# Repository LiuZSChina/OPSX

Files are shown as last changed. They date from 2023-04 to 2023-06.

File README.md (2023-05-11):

# OPSX Sonnar
An open sourced Polaroid SX-70 core board with sonnar support.Based on the [OPSX project](https://github.com/sunyitong/OPSX).\
开源的宝丽来sx-70核心板，可以支持带有声呐对焦的设备。基于[OPSX 项目](https://github.com/sunyitong/OPSX)开发。

This is an open sourced Polaroid SX-70 instant camera core board with the Raspberry Pi RP2040 as the MCU. The aim of this project is to provide a fully resource accessible and hobbyist friendly replacement core board. It offers more extensibility and hacking ideas while implementing all the features of the original camera.\
本项目是开源的宝丽来sx-70核心板，该项目使用树莓派rp2040构建而成，本项目的目的是为爱好者提供一个可以完全自主掌控的核心板，在保留原机器各种功能的同时可以发挥自己的创意进行功能拓展。

The structure of the repository:\
本项目仓库的结构：

1. The [Original](https://github.com/LiuZSChina/OPSX/tree/master/Original) file contains design for non-sonnar sx-70.See README.md inside this folder for details.\
[Original](https://github.com/LiuZSChina/OPSX/tree/master/Original)文件夹内是适合没有声呐对焦sx70的核心板设计，设计来自于原本的[OPSX 项目](https://github.com/sunyitong/OPSX)，文件夹内具体项目的作用详见文件夹内的README.md

2. The [Sonar](https://github.com/LiuZSChina/OPSX/tree/master/Sonnar) file contains design for sonnar sx-70.See README.md inside this folder for details.\
[Original](https://github.com/LiuZSChina/OPSX/tree/master/Original)文件夹内是新设计的适用于声呐对焦的sx70核心板及附件，文件夹内具体项目的作用详见文件夹内的README.md。

## Table of Contents

- [OPSX](#opsx)
  - [Hardware](#hardware)
    - [Fabrication](#fabrication)
  - [Software](#software)
    - [Uploading](#uploading)
  - [Contributor](#contributor)
  - [License](#license)

## Hardware
> Remander: You are going to need some “basic” tools:   soldering iron with a fine tip, a prying tool and a tweezer.\
Aside from the usual tools you are going to need what is called a “Polaroid screwdriver” or “SX-70 screwdriver”, since most of the cameras use a special “square 1mm x 1mm” screws. You could either buy one or fabricate one yourself.\
please read the [Disassembly Guide](https://instantphotography.files.wordpress.com/2010/12/polaroid-sx-70-camera-repair-book.pdf) or [SX70 camera 125ASA to 600ASA conversion](https://opensx70.com/tutorials/100-600-conversion/) first.\
提示：首先你需要一些基本的工具：电烙铁、撬棒和镊子。\
其次大多数sx70相机的螺丝都是非常特殊的1mm x 1mm 宝丽来螺丝，所以你需要使用特殊的螺丝刀才能拆卸，买一把或者自己磨一个都可以。\
在操作之前推荐先浏览[Disassembly Guide](https://instantphotography.files.wordpress.com/2010/12/polaroid-sx-70-camera-repair-book.pdf) 或者 [SX70 camera 125ASA to 600ASA conversion](https://opensx70.com/tutorials/100-600-conversion/).

### Fabrication
Please select a **dual copper layer PCB** with a thickness of **0.8 mm** or less for fabrication.\
制造时请选择 FR-4基板，双层板，厚度0.8mm或者更小（会贵）。

## Software
TODO

### Uploading
Solder U+ U- GND VCC to a standard usb cable to connect to your computer. Then you can treat it as normal raspberry pico device. See [here](https://www.raspberrypi.com/documentation/microcontrollers/rp2040.html#raspberry-pi-pico) for more information about uploading.\
把板子上的U+ U- GND VCC焊到usb线上，连接电脑后可以当作树莓派Pico开发板进行操作，具体上传的方法在[这里](https://www.raspberrypi.com/documentation/microcontrollers/rp2040.html#raspberry-pi-pico)。

## Contributor
[@Yitong Sun](https://github.com/sunyitong) - a PhD candidate in the Computer Science Research Centre at the Royal College of Art.[RCA website](https://www.rca.ac.uk/research-innovation/research-degrees/research-students/yitong-sun/) - [E-mail](yitong.sun@network.rca.ac.uk)

[@LiuZS](https://github.com/LiuZSChina) - ？
## License
Any distribution or modification based on this project should be clearly attributed to the source.
[GPL 3.0](LICENSE)

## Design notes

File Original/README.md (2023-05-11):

# OPSX
An open sourced Polaroid SX-70 core board

This is an open sourced Polaroid SX-70 instant camera core board with the Raspberry Pi RP2040 as the MCU. The aim of this project is to provide a fully resource accessible and hobbyist friendly replacement core board. It offers more extensibility and hacking ideas while implementing all the features of the original camera.

The structure of the repository:

1. The [bom](https://github.com/LiuZSChina/OPSX/tree/master/Original/bom) folder contains an html-based interactive bill of material. You can use it to find the component types and locations

2. The [code](https://github.com/LiuZSChina/OPSX/tree/master/Original/code) folder holds the program files necessary to run the core board. The programs are implemented in two separate programming languages:

   - [Micropython](https://docs.micropython.org/en/latest/rp2/quickref.html): Similar syntax to python, easy to modify and testing.
   - [Rust](https://docs.rs/rp2040/latest/rp2040/) (TODO): Ultimate performance with zero runtime loss.

3. The [gerber](https://github.com/LiuZSChina/OPSX/tree/master/Original/gerber) folder stores the PCB files necessary for factory production.

4. The [schematic](https://github.com/LiuZSChina/OPSX/tree/master/Original/schematic) folder holds a PDF file which illustrating the circuit principles.

## Table of Contents

- [OPSX](#opsx)
  - [Table of Contents](#table-of-contents)
  - [Hardware](#hardware)
    - [Fabrication](#fabrication)
  - [Software](#software)
    - [Uploading](#uploading)
  - [Contributor](#contributor)
  - [License](#license)

## Hardware
TODO
> Remander: Special tools are required to replace the original core board, please read the [Disassembly Guide](https://instantphotography.files.wordpress.com/2010/12/polaroid-sx-70-camera-repair-book.pdf) first.
### Fabrication
Please select a **dual copper layer PCB** with a thickness of **0.8 mm** or less for fabrication.
## Software
TODO
### Uploading
TODO
## Contributor
[@Yitong Sun](https://github.com/sunyitong) - a PhD candidate in the Computer Science Research Centre at the Royal College of Art.

[RCA website](https://www.rca.ac.uk/research-innovation/research-degrees/research-students/yitong-sun/) - [E-mail](yitong.sun@network.rca.ac.uk)
## License
Any distribution or modification based on this project should be clearly attributed to the source.
[GPL 3.0](LICENSE) © Yitong Sun

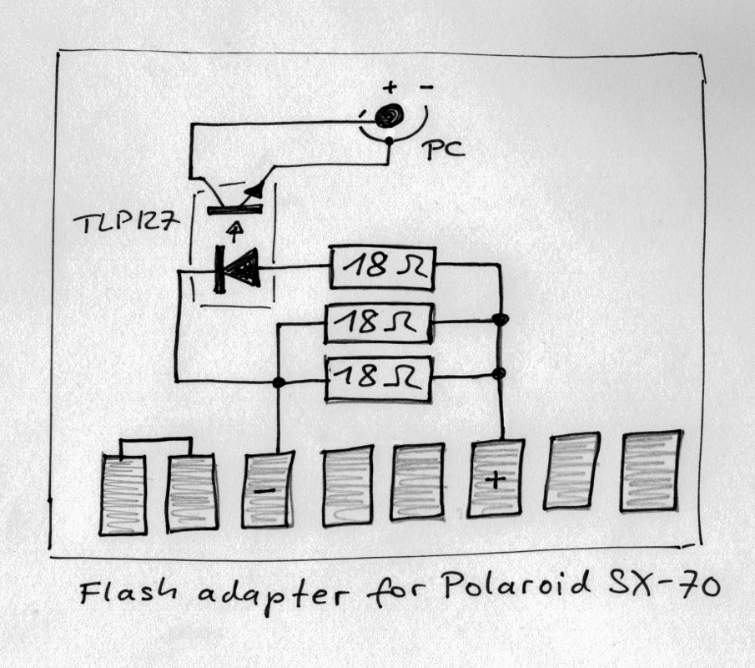
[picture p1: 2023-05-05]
Sonnar/Flash_Plug/adaptercircuit2.jpg

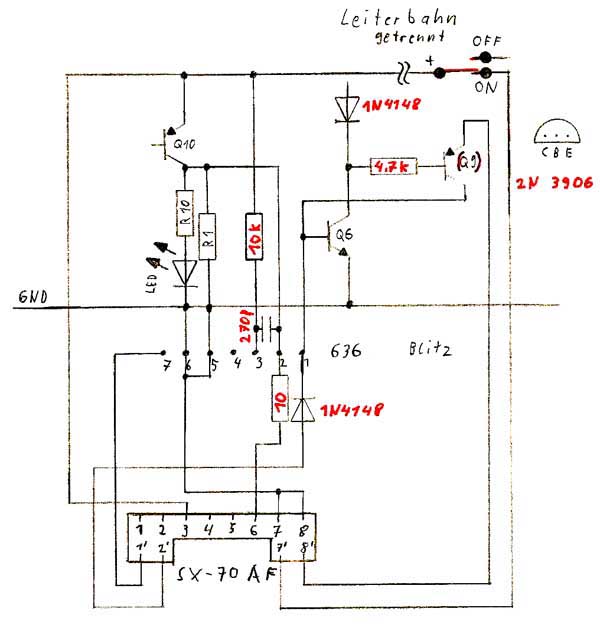
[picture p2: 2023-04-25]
Sonnar/Flash_Plug/Flash-schaltplan2.jpg

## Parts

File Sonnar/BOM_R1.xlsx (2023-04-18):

Comment | Designator | Footprint | 嘉立创元件编号
100nF | C1,C2,C4,C6,C7,C8,C9,C10,C11,C12,C14 | 0402_C | C307331
1uF | C3,C5,C13 | 0402_C | C52923
13pF | C15 | 0402_C | C541433
1N4148WS | D1,D3,D4 | D_SOD-323 | C2128
LED | D5 | 0603_D | C72041
LED | D6 | 0603_D | C72038
Q_NMOS_GSD | Q1,Q2 | SOT-23 | C23521
Q_PMOS_GSD | Q3 | SOT-23 | C8549
MMBT3904 | Q4 | SOT-23 | C20526
27.4Ω | R1,R2 | 0402_R | C102945
1kΩ | R3,R26,R27,R35 | 0402_R | C11702
10kΩ | R4,R6,R9,R11,R12,R13,R15,R17,R19 | 0402_R | C25744
12kΩ | R5,R10,R14,R16,R18,R20 | 0402_R | C25752
22kΩ | R7 | 0805_R | C25768
100kΩ | R8,R23,R25,R28 | 0402_R | C25741
120Ω | R21,R22,R24 | 0402_R | C25079
180Ω | R29 | 0402_R | C174173
150Ω | R30 | 0402_R | C25082
5.6kΩ | R31 | 0402_R | C25908
47kΩ | R32 | 0402_R | C25792
2.7kΩ | R33 | 0402_R | C352444
330Ω | R34 | 0402_R | C25104
RP2040 | U1 | LQFN-56(7x7) | C2040
TLV70430DBVR | U2 | SOT-23-5 | C133625
W25Q128JVS | U3 | SOIC-8_5.23x5.23mm_P1.27mm | C97521
AD8605 | U5,U6 | TSOT-23-5 | C9641
Crystal_GND2 | Y1 | Resonator_SMD_Murata_CSTxExxV-3Pin_3.0x1.1mm | C91581

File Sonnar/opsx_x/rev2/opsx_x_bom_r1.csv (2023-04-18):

ID | 指示符 | 封装 | 数量 | 名称 | 供应商和参考
1 | U4 | TMB6-1.55-3.8X2.6MM | 1 | OPTICAL-TSL2561T(6P-3.8X2.6MM)
2 | U2 | DBV0005A_N | 1 | TLV70430DBVR
3 | R35,R27,R26,R3 | R_0402_1005Metric_Pad0.72x0.64mm_HandSolder | 4 | 1k
4 | D6,D5 | D_0603_1608Metric_Pad1.05x0.95mm_HandSolder | 2 | LED
5 | R34 | R_0402_1005Metric_Pad0.72x0.64mm_HandSolder | 1 | 330
6 | Q3 | SOT-23 | 1 | Q_PMOS_GSD
7 | R33 | R_0402_1005Metric_Pad0.72x0.64mm_HandSolder | 1 | 2.7k
8 | R32 | R_0402_1005Metric_Pad0.72x0.64mm_HandSolder | 1 | 47k
9 | R31 | R_0402_1005Metric_Pad0.72x0.64mm_HandSolder | 1 | 5.6k
10 | Q4 | SOT-23 | 1 | MMBT3904
11 | Z3,Z2,Z1 | Selector_default | 3 | ~
12 | R30 | R_0402_1005Metric_Pad0.72x0.64mm_HandSolder | 1 | 150
13 | R29 | R_0402_1005Metric_Pad0.72x0.64mm_HandSolder | 1 | 180
14 | C15 | C_0402_1005Metric_Pad0.74x0.62mm_HandSolder | 1 | 13p
15 | U6,U5 | TSOT-23-5 | 2 | AD8603
16 | R28,R8,R25,R23 | R_0402_1005Metric_Pad0.72x0.64mm_HandSolder | 4 | 100k
17 | R7 | R_0805_2012Metric_Pad1.20x1.40mm_HandSolder | 1 | 22k
18 | R10,R16,R14,R18,R5,R20 | R_0402_1005Metric_Pad0.72x0.64mm_HandSolder | 6 | 12k
19 | C8,C14,C6,C2,C10,C12,C7,C1,C9,C11 | C_0402_1005Metric_Pad0.74x0.62mm_HandSolder | 10 | 100n
20 | R12,R15,R6,R19,R9,R17,R11,R4,R13 | R_0402_1005Metric_Pad0.72x0.64mm_HandSolder | 9 | 10k
21 | R1,R2 | R_0402_1005Metric_Pad0.72x0.64mm_HandSolder | 2 | 27.4
22 | Q2,Q1 | SOT-23 | 2 | Q_NMOS_GSD
23 | sx1 | sx70 | 1 | sx~
24 | J2,J1,J3 | PinHeader_1x02_P2.54mm_Vertical | 3 | Conn_01x02
25 | C4 | C_0402_1005Metric_Pad0.74x0.62mm_HandSolder | 1 | 0.1u
26 | Y1 | Resonator_SMD_Murata_CSTxExxV-3Pin_3.0x1.1mm | 1 | Crystal_GND2
27 | D4,D3,D1 | D_SOD-323 | 3 | 1N4148WS
28 | R24,R21,R22 | R_0402_1005Metric_Pad0.72x0.64mm_HandSolder | 3 | 100
29 | U3 | SOIC-8_5.23x5.23mm_P1.27mm | 1 | W25Q128JVS
30 | C3,C13,C5 | C_0402_1005Metric_Pad0.74x0.62mm_HandSolder | 3 | 1u
31 | U1 | RP2040-QFN-56 | 1 | RP2040
32 | D2 | Osram_SFH2430 | 1 | SFH2430

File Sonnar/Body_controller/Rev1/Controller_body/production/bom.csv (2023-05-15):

Designator | Footprint | Quantity | Value | LCSC Part #
Bolt1, Bolt2, Bolt3 | M3_Bolt | 3 | ~
J1 | TE_84953-6_1x06-1MP_P1.0mm_Horizontal | 1 | Conn_01x06_Socket
J2 | PinHeader_1x03_P2.54mm_Horizontal | 1 | Conn_01x03_Socket
R1, R10, R11, R12, R13, R2, R3, R4, R7, R8, R9 | 805 | 11 | 100k
R5, R6 | 805 | 2 | 10k
SW1 | GSMR_16 | 1 | ~
SW2 | GSMR_10S | 1 | ~
SW3 | Direction3 Pin5 | 1 | ~
U1 | SOP65P640X120-24N | 1 | PCF8575PWR
U2 | OLED 0.96 i2c | 1 | ~

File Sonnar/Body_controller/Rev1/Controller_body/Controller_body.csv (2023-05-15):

# | Reference | Qty | Value | Footprint | DNP
1 | Bolt1, Bolt2, Bolt3 | 3 | ~ | 0JIMMY:M3_Bolt
2 | J1 | 1 | Conn_01x06_Socket | Connector_FFC-FPC:TE_84953-6_1x06-1MP_P1.0mm_Horizontal
3 | J2 | 1 | Conn_01x03_Socket | Connector_PinHeader_2.54mm:PinHeader_1x03_P2.54mm_Horizontal
4 | R1, R2, R3, R4, R7, R8, R9, R10, R11, R12, R13 | 11 | 100k | Resistor_SMD:R_0805_2012Metric_Pad1.20x1.40mm_HandSolder
5 | R5, R6 | 2 | 10k | Resistor_SMD:R_0805_2012Metric_Pad1.20x1.40mm_HandSolder
6 | SW1 | 1 | ~ | SW_CODED:GSMR_16
7 | SW2 | 1 | ~ | SW_CODED:GSMR_10S
8 | SW3 | 1 | ~ | SW_CODED:Direction3 Pin5
9 | U1 | 1 | PCF8575PWR | SOP65P640X120-24N
10 | U2 | 1 | ~ | 0JIMMY:OLED 0.96 i2c

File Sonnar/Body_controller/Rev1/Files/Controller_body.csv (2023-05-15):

ID | 指示符 | 封装 | 数量 | 名称 | 供应商和参考
1 | R6,R5 | R_0805_2012Metric_Pad1.20x1.40mm_HandSolder | 2 | 10k
2 | R8,R3,R12,R2,R10,R7,R13,R4,R11,R9,R1 | R_0805_2012Metric_Pad1.20x1.40mm_HandSolder | 11 | 100k
3 | Bolt2,Bolt3,Bolt1 | M3_Bolt | 3 | ~
4 | J1 | TE_84953-6_1x06-1MP_P1.0mm_Horizontal | 1 | Conn_01x06_Socket
5 | SW3 | Direction3 Pin5 | 1 | ~
6 | U2 | OLED 0.96 i2c | 1 | ~
7 | J2 | PinHeader_1x03_P2.54mm_Horizontal | 1 | Conn_01x03_Socket
8 | SW1 | GSMR_16 | 1 | ~
9 | U1 | SOP65P640X120-24N | 1 | PCF8575PWR
10 | SW2 | GSMR_10S | 1 | ~

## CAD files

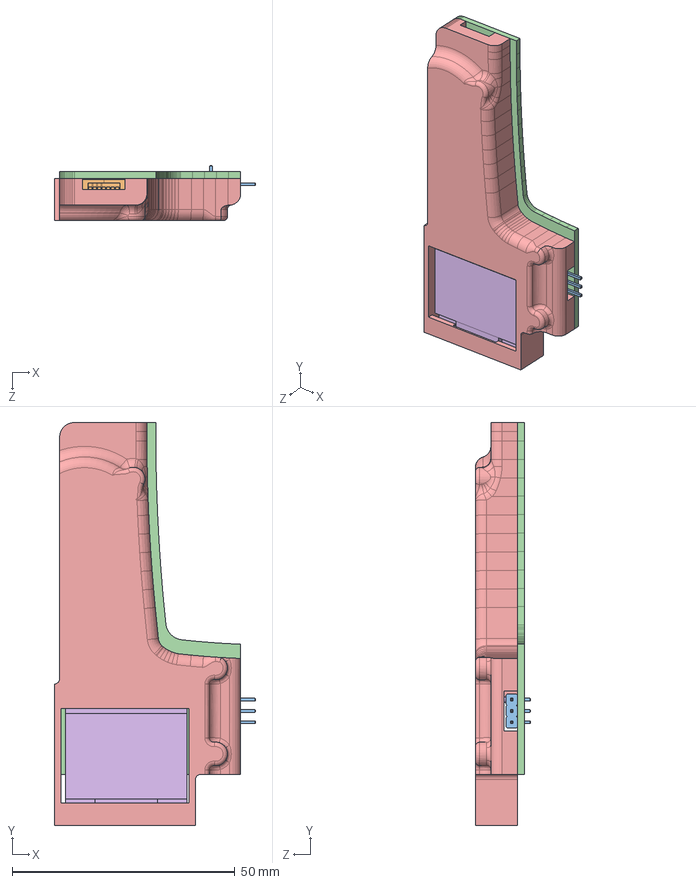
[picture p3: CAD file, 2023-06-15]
Sonnar/Body_controller/Rev1/3D/机身.SLDASM
45.2 x 90.5 x 12.4 mm
SOLID.step x 13
SOLID-0.step
SOLID-1.step
PCB.step
机身壳
oled

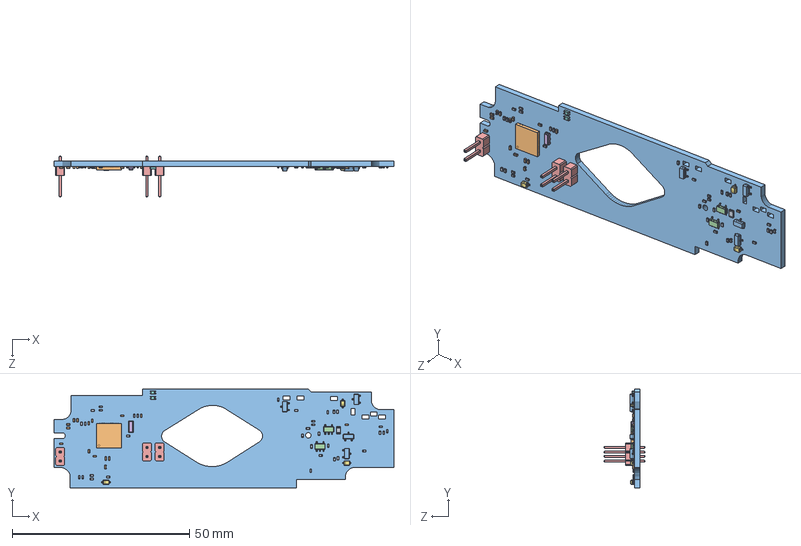
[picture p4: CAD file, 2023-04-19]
Sonnar/3D/opsx_x.SLDASM
95.9 x 27.8 x 11.5 mm
SOLID.step x 34
SOLID-0.step x 15
SOLID-1.step x 4
SOLID-2.step x 2
SOLID-3.step x 3
SOLID-4.step
SOLID-5.step x 3
SOLID-6.step x 2
SOLID-7.step
SOLID-8.step
PCB.step

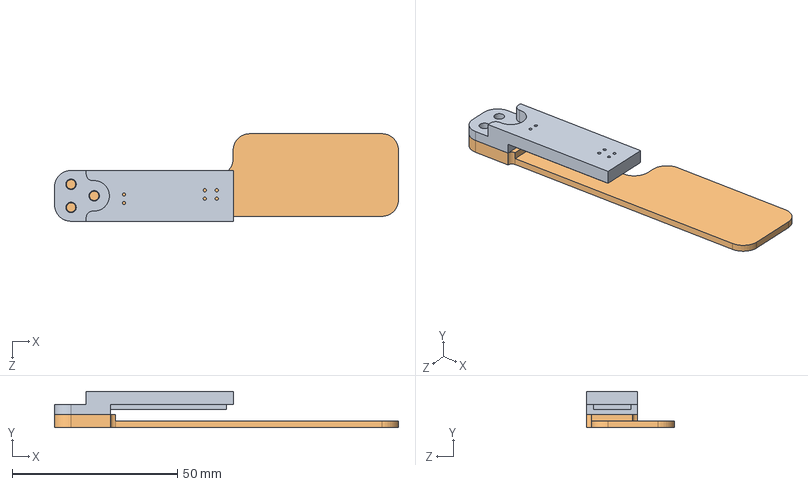
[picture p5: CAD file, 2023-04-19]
Sonnar/3D/测试夹.SLDASM
104.0 x 11.0 x 26.5 mm
测试针
测试针_底

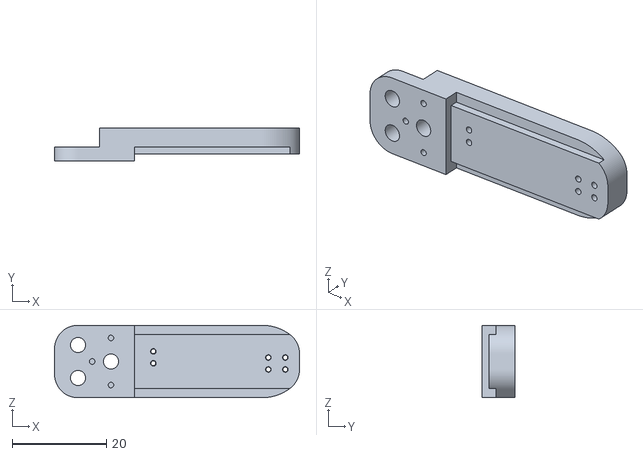
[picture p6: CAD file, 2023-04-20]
Sonnar/3D/Test_Pin_Holder.STL
52.0 x 7.00 x 15.4

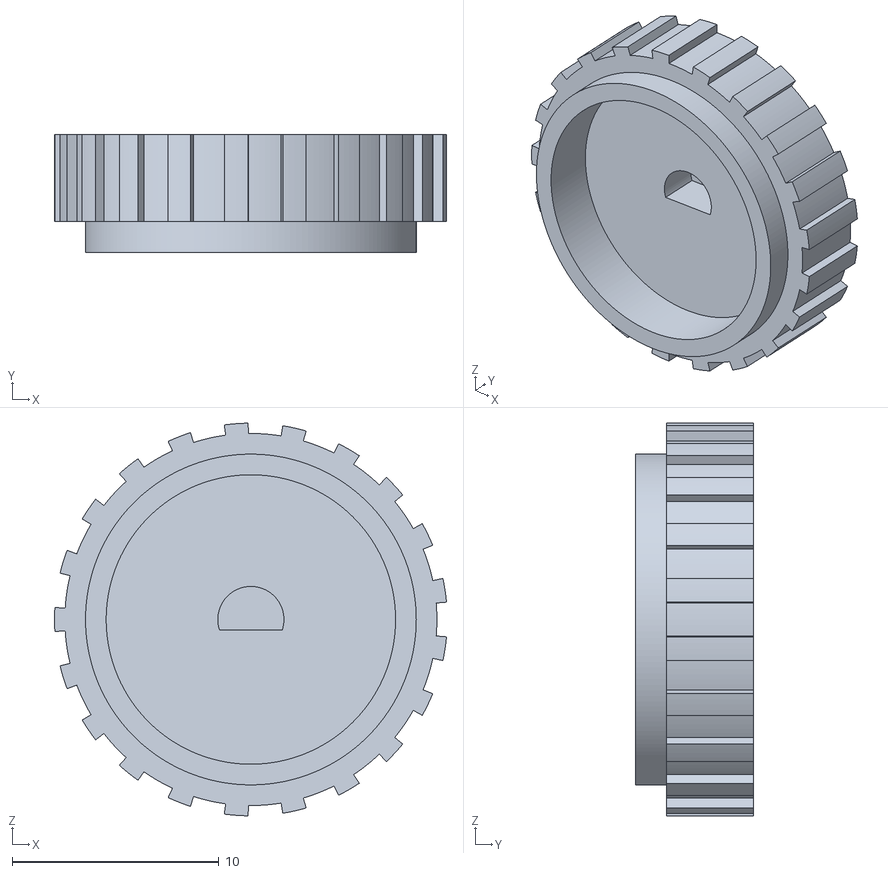
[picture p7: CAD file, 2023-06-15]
Sonnar/Body_controller/Rev1/3D/rot_no_val_th.stl
19.0 x 5.70 x 19.0

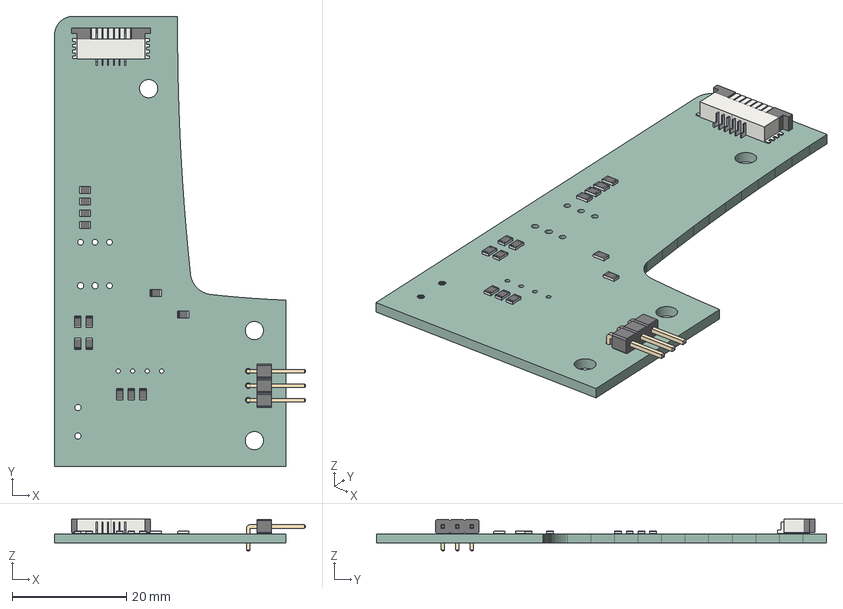
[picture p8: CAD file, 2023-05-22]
Sonnar/Body_controller/Rev1/Controller_body/3D/Controller_body.step
44.0 x 79.0 x 5.56 mm
PCB

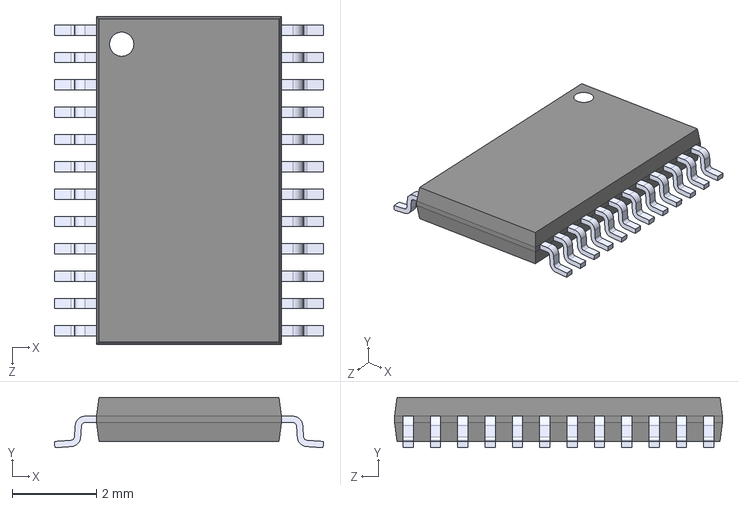
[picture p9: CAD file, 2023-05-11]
Sonnar/Body_controller/Rev1/Controller_body/PCF8575PWR/PCF8575PWR.step
6.40 x 1.20 x 7.80 mm

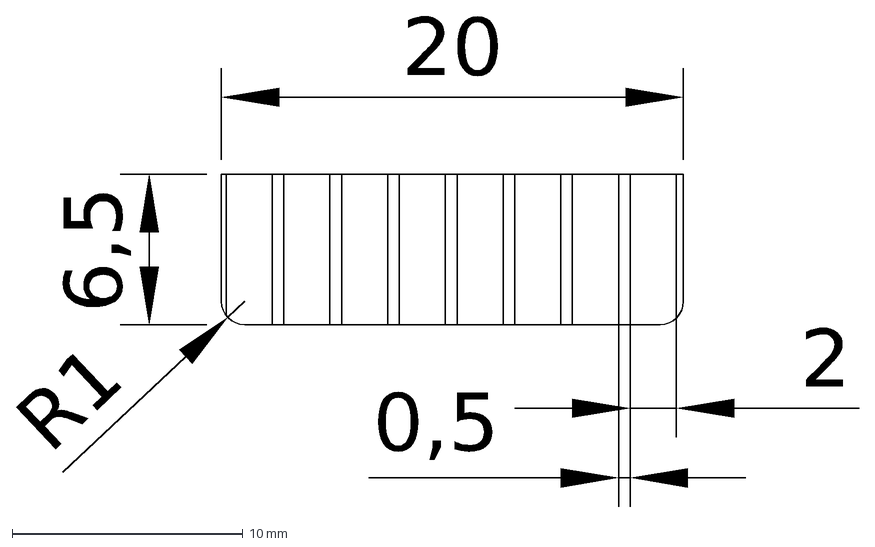
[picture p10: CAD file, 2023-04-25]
Sonnar/Flash_Plug/Flash_Plug_Size.dxf
20
6,5
R1
2
0,5

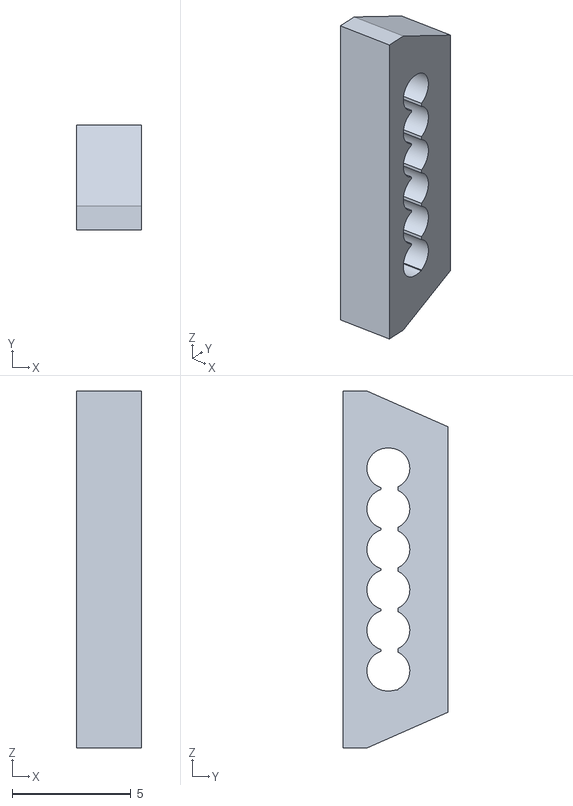
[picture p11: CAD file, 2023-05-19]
Sonnar/opsx_x/3D/line_cliper_round.stl
2.75 x 4.40 x 15.0

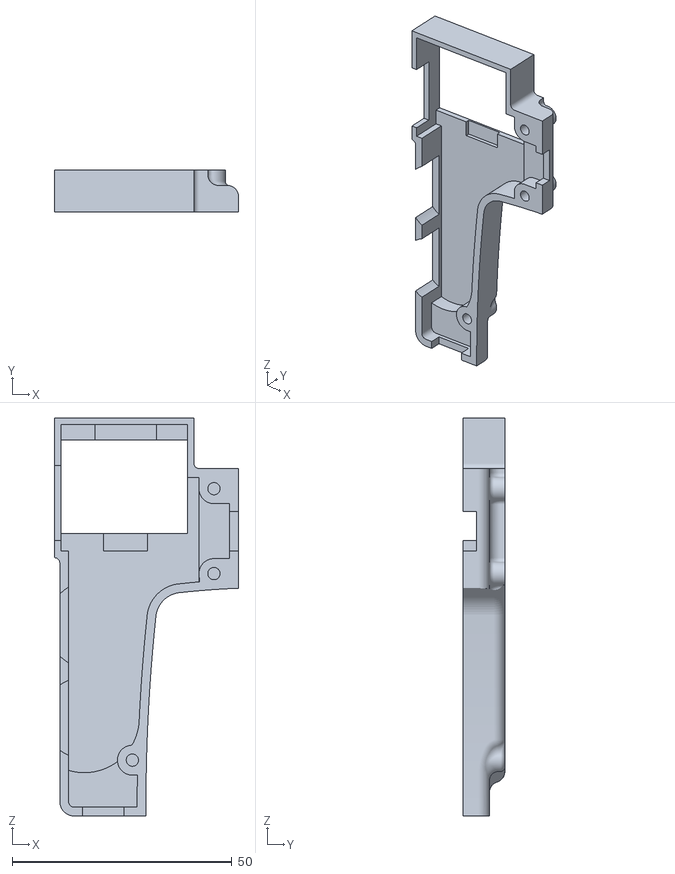
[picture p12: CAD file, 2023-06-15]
Sonnar/Body_controller/Rev1/3D/Case_Body_Control.STL
41.8 x 9.50 x 90.5

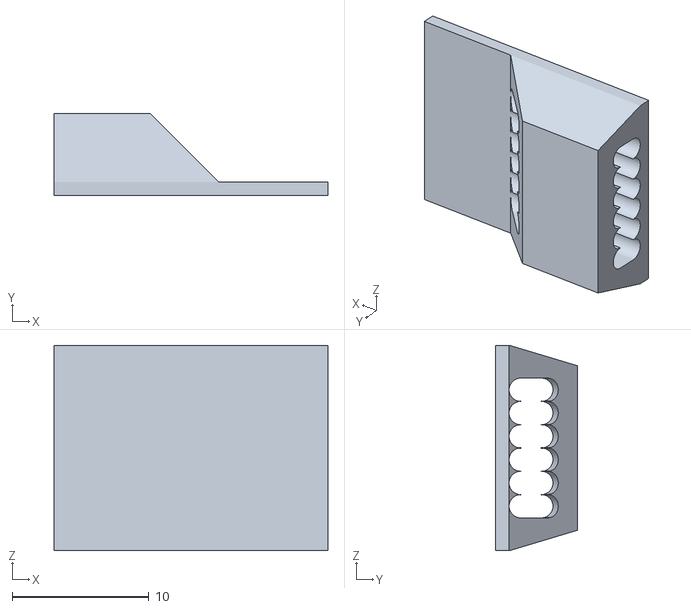
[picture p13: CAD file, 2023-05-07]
Sonnar/opsx_x/3D/line_cliper_reverse.stl
20.0 x 6.00 x 15.0

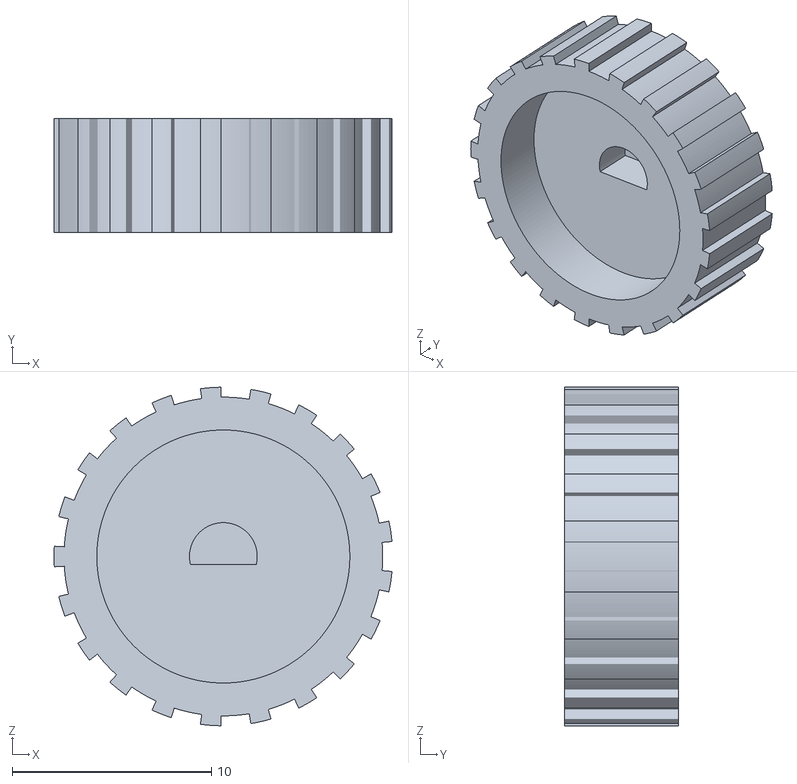
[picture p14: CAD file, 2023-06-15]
Sonnar/Body_controller/Rev1/3D/rot_no_val_sec_th.stl
17.0 x 5.70 x 17.0

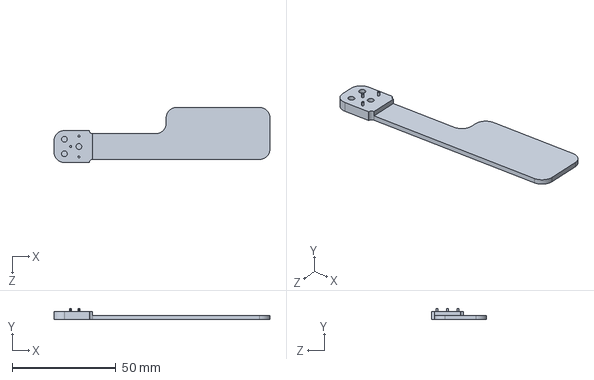
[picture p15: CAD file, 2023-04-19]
Sonnar/3D/测试针_底.STEP
104.0 x 5.50 x 26.5 mm

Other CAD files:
Sonnar/Body_controller/sx-70-skin-sholder.dxf
Sonnar/3D/测试针.SLDPRT
Sonnar/Body_controller/sx-70-skin-template-vector-v1.10-empty.dwg
Sonnar/3D/test_pin.STEP
Sonnar/3D/Test_pin_bottom_bare_pcb.STL
Sonnar/3D/opsx_x.DXF
Sonnar/3D/opsx_x.SLDDRW
Sonnar/3D/opsx_x.dwg
Sonnar/3D/测试针_底.SLDPRT
Sonnar/Body_controller/Rev1/3D/OldVersions/rot_th.0006.ipt
Sonnar/Body_controller/Rev1/3D/oled.SLDPRT
Sonnar/Body_controller/Rev1/3D/rot_no_val_sec_th.ipt
Sonnar/Body_controller/Rev1/3D/rot_no_val_th.ipt
Sonnar/Body_controller/Rev1/3D/rot_th.ipt
Sonnar/Body_controller/Rev1/3D/rot_th.stl
Sonnar/Body_controller/Rev1/3D/机身壳.SLDPRT
Sonnar/Body_controller/Rev1/3D/机身壳.STEP
Sonnar/Body_controller/Rev1/3D/机身壳.STL
Sonnar/Body_controller/Rev1/Controller_body/3D/Controller_body.DXF
Sonnar/Body_controller/Rev1/Controller_body/3D/Controller_body.SLDASM
Sonnar/Body_controller/Rev1/Controller_body/3D/Controller_body.dwg
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

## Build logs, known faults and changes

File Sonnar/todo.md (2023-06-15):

### ~~接线器~~
1. ~~焊接~~ 2023.5.25
2.  ~~理线卡子3D~~ 2023.5.20
3. ~~打印理线卡子~~ 2023.5.2

### 代码
1. ~~填充闪光（> 1/30 的进行填充）~~ 23.5.20
2. 测光magic number 
3. ~~pcf8575控制代码~~ 23.5.30
4. 显示内容优化
5. ~~读取旋钮的值并且转换为快门速度~~ 23.5.30
6. T门逻辑更改为使用旋钮设置

### 机身控制器
1. ~~焊接元件~~ 23.5.30
2. ~~波轮建模~~ 23.5.30
3. ~~波轮打印~~ 23.5.30
4. 升级版壳子

### 测试
1. ~~填充闪光~~ 23.5.30
2. ~~与机身控制器通讯~~ 23.5.30
3. ~~组合机身~~ 23.5.30

### 工程
1. 申请与原本工程合并

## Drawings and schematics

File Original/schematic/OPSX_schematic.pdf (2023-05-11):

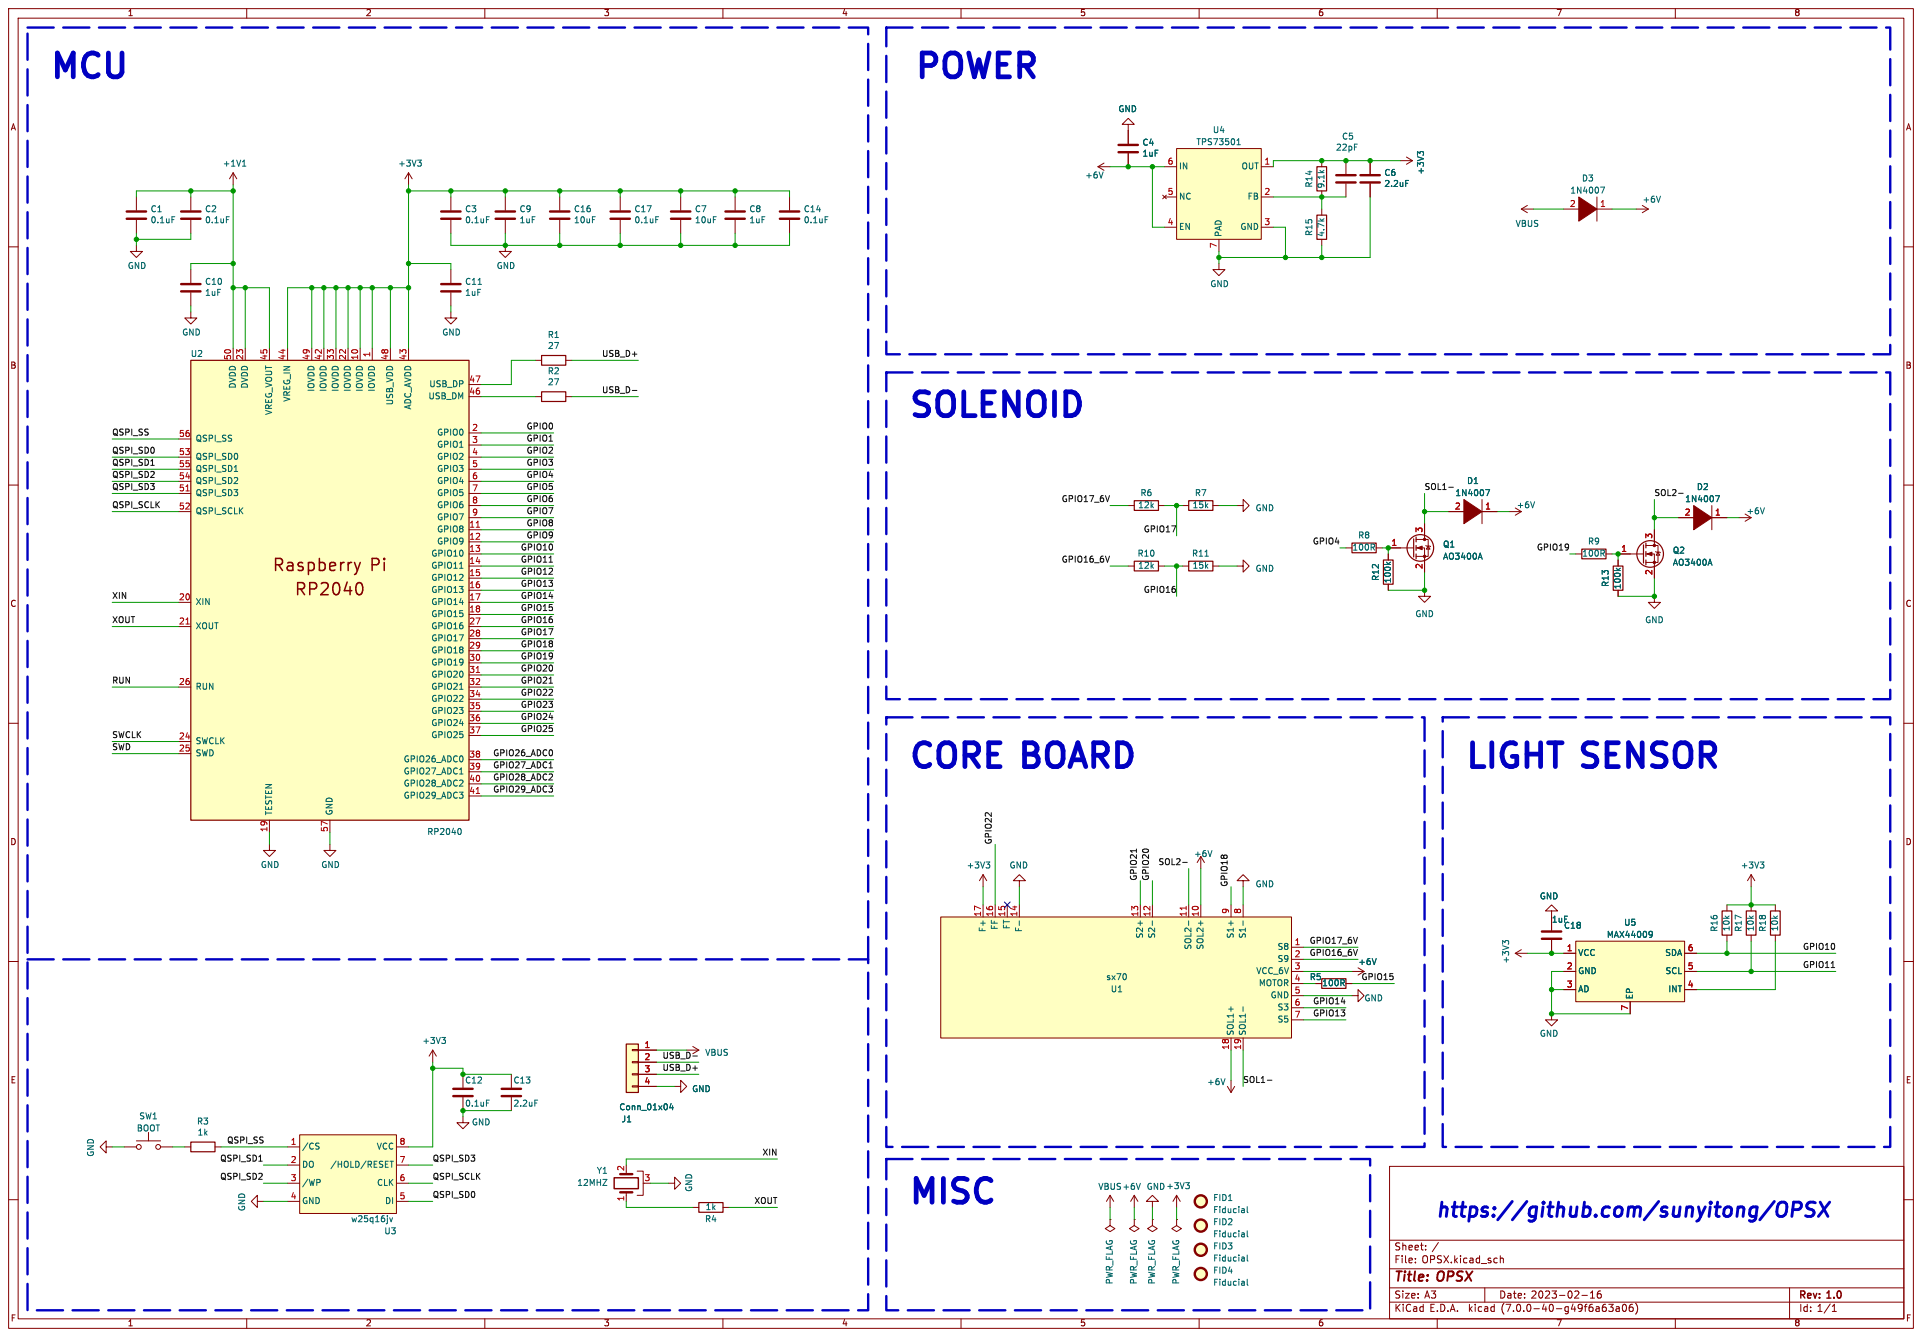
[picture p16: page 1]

1 IOVDD 10 GPIO8 11 GPIO9 12 GPIO10 13 GPIO11 14 GPIO12 15 GPIO13 16 GPIO14 17 GPIO15 18 TESTEN 19 GPIO0 2 XIN 20 XOUT 21 IOVDD 22 DVDD 23 SWCLK 24 SWD 25 RUN 26 GPIO16 27 GPIO17 28 GPIO18 29 GPIO1 3 GPIO19 30 GPIO20 31 GPIO21 32 IOVDD 33 GPIO22 34 GPIO23 35 GPIO24 36 GPIO25 37 GPIO26_ADC0 38 GPIO27_ADC1 39 GPIO2 4 GPIO28_ADC2 40 GPIO29_ADC3 41 IOVDD 42 ADC_AVDD 43 VREG_IN 44 VREG_VOUT 45 USB_DM 46 USB_DP 47 USB_VDD 48 IOVDD 49 GPIO3 5 DVDD 50 QSPI_SD3 51 QSPI_SCLK 52 QSPI_SD0 53 QSPI_SD2 54 QSPI_SD1 55 QSPI_SS 56 GND 57 GPIO4 6 GPIO5 7 GPIO6 8 GPIO7 9 U2 RP2040 GND

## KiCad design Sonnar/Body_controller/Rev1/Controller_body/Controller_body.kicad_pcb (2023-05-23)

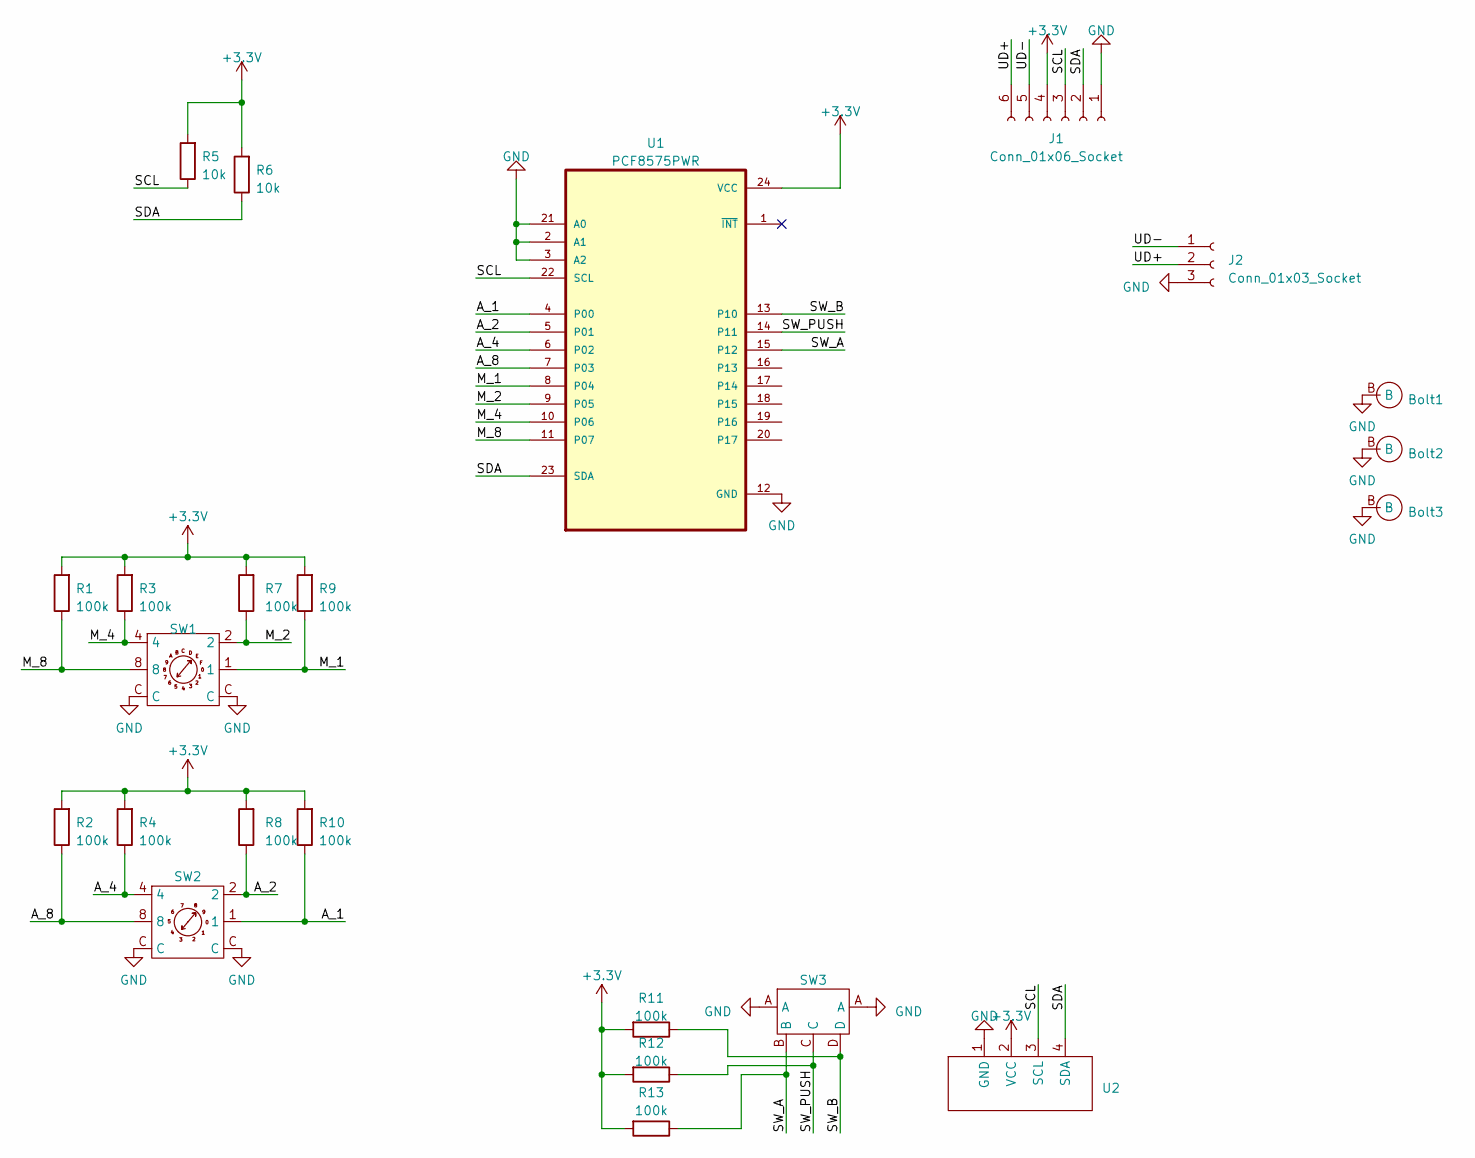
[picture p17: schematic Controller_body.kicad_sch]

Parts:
Bolt1, Bolt2, Bolt3: M3_Bolt
J1: Conn_01x06_Socket; TE_84953-6_1x06-1MP_P1.0mm_Horizontal
J2: Conn_01x03_Socket; PinHeader_1x03_P2.54mm_Horizontal
R1, R2, R3, R4, R7, R8, R9, R10, R11, R12, R13: 100k; R_0805_2012Metric_Pad1.20x1.40mm_HandSolder
R5, R6: 10k; R_0805_2012Metric_Pad1.20x1.40mm_HandSolder
SW1: GSMR_16
SW2: GSMR_10S
SW3: Direction3 Pin5
U1: PCF8575PWR; SOP65P640X120-24N
U2: OLED 0.96 i2c

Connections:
+3.3V: J1.4, R1.2, R2.2, R3.2, R4.2, R5.2, R6.2, R7.2, R8.2, R9.2, R10.2, R11.2, R12.2, R13.2, U1.24 (VCC), U2.2 (VCC)
/A_1: R10.1, SW2.1, U1.4 (P00)
/A_2: R8.1, SW2.2, U1.5 (P01)
/A_4: R4.1, SW2.4, U1.6 (P02)
/A_8: R2.1, SW2.8, U1.7 (P03)
/M_1: R9.1, SW1.1, U1.8 (P04)
/M_2: R7.1, SW1.2, U1.9 (P05)
/M_4: R3.1, SW1.4, U1.10 (P06)
/M_8: R1.1, SW1.8, U1.11 (P07)
/SCL: J1.3, R5.1, U1.22 (SCL), U2.3 (SCL)
/SDA: J1.2, R6.1, U1.23 (SDA), U2.4 (SDA)
/SW_A: R13.1, SW3.B, U1.15 (P12)
/SW_B: R11.1, SW3.D, U1.13 (P10)
/SW_PUSH: R12.1, SW3.C, U1.14 (P11)
/UD+: J1.6, J2.2
/UD-: J1.5, J2.1
GND: Bolt1.B, Bolt2.B, Bolt3.B, J1.1, J2.3, SW1.C, SW2.C, SW3.A, U1.2 (A1), U1.3 (A2), U1.12 (GND), U1.21 (A0), U2.1 (GND)

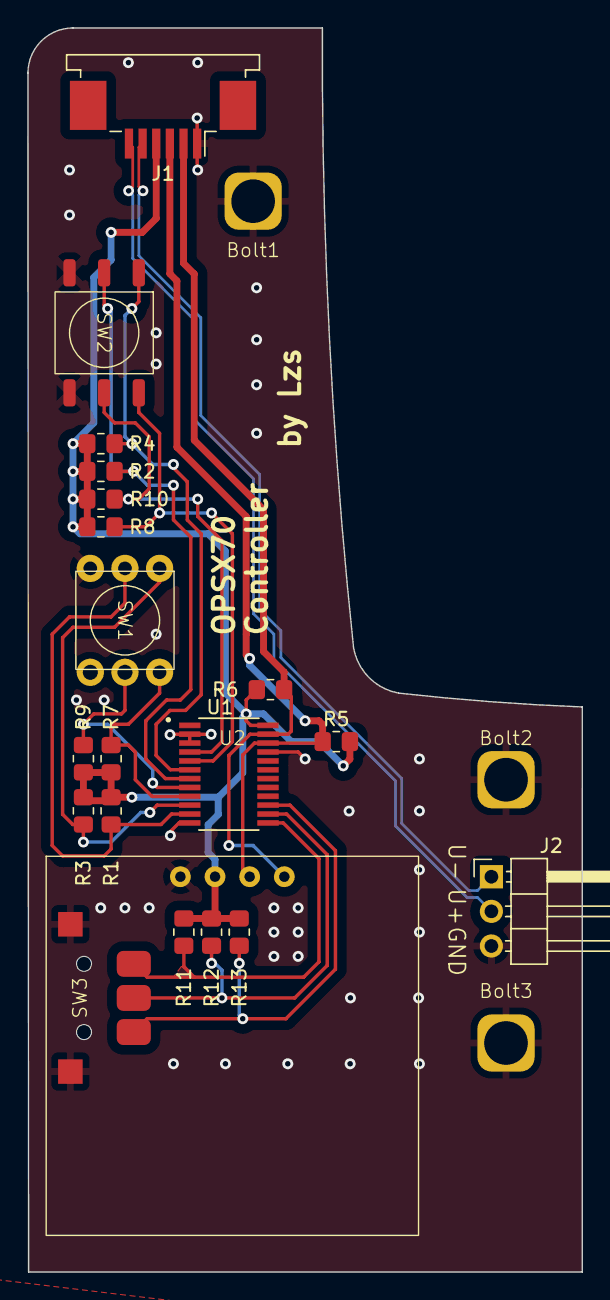
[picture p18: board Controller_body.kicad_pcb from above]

Board: 2 copper layers, 40.6 x 91.2 mm, 23 parts (0 on the bottom side), 17 nets.

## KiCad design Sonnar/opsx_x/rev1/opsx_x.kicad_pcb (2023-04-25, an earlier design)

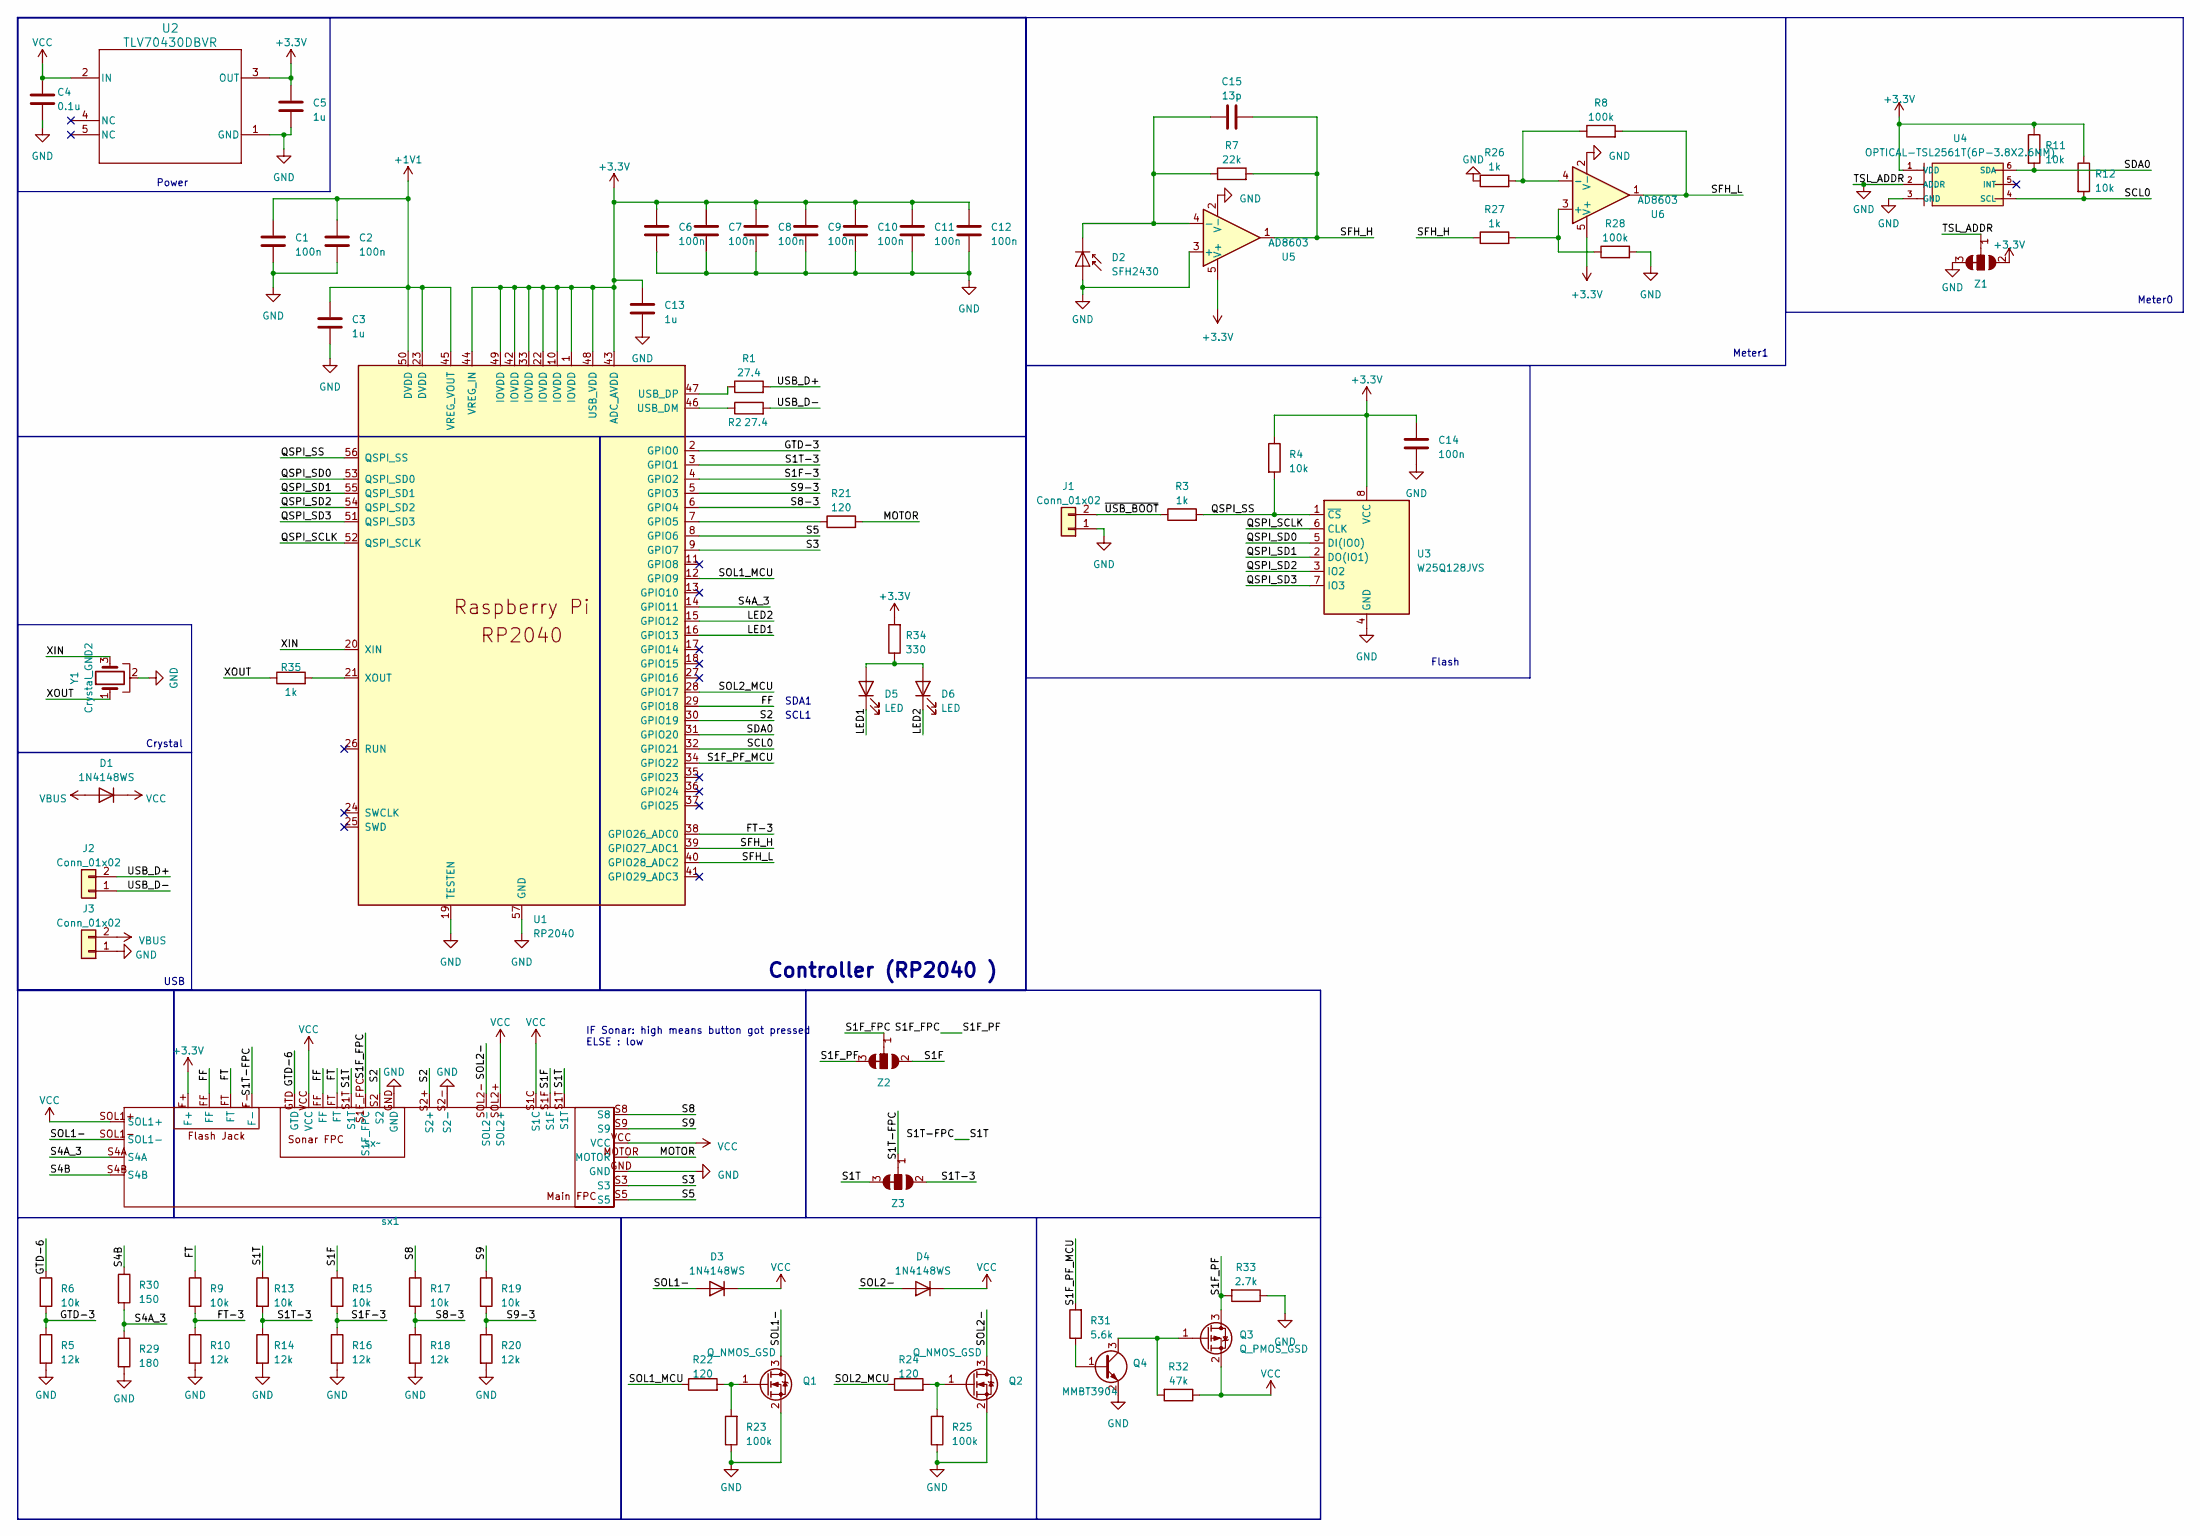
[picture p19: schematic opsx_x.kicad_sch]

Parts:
C1, C2, C6, C7, C8, C9, C10, C11, C12, C14: 100n; C_0402_1005Metric_Pad0.74x0.62mm_HandSolder
C3, C5, C13: 1u; C_0402_1005Metric_Pad0.74x0.62mm_HandSolder
C4: 0.1u; C_0402_1005Metric_Pad0.74x0.62mm_HandSolder
C15: 13p; C_0402_1005Metric_Pad0.74x0.62mm_HandSolder
D1, D3, D4: 1N4148WS; D_SOD-323
D2: SFH2430; Osram_SFH2430
D5, D6: LED; D_0603_1608Metric_Pad1.05x0.95mm_HandSolder
J1, J2, J3: Conn_01x02; PinHeader_1x02_P2.54mm_Vertical
Q1, Q2: Q_NMOS_GSD; SOT-23
Q3: Q_PMOS_GSD; SOT-23
Q4: MMBT3904; SOT-23
R1, R2: 27.4; R_0402_1005Metric_Pad0.72x0.64mm_HandSolder
R3, R26, R27, R35: 1k; R_0402_1005Metric_Pad0.72x0.64mm_HandSolder
R4, R6, R9, R11, R12, R13, R15, R17, R19: 10k; R_0402_1005Metric_Pad0.72x0.64mm_HandSolder
R5, R10, R14, R16, R18, R20: 12k; R_0402_1005Metric_Pad0.72x0.64mm_HandSolder
R7: 22k; R_0805_2012Metric_Pad1.20x1.40mm_HandSolder
R8, R23, R25, R28: 100k; R_0402_1005Metric_Pad0.72x0.64mm_HandSolder
R21, R22, R24: 120; R_0402_1005Metric_Pad0.72x0.64mm_HandSolder
R29: 180; R_0402_1005Metric_Pad0.72x0.64mm_HandSolder
R30: 150; R_0402_1005Metric_Pad0.72x0.64mm_HandSolder
R31: 5.6k; R_0402_1005Metric_Pad0.72x0.64mm_HandSolder
R32: 47k; R_0402_1005Metric_Pad0.72x0.64mm_HandSolder
R33: 2.7k; R_0402_1005Metric_Pad0.72x0.64mm_HandSolder
R34: 330; R_0402_1005Metric_Pad0.72x0.64mm_HandSolder
U1: RP2040; RP2040-QFN-56
U2: TLV70430DBVR; DBV0005A_N
U3: W25Q128JVS; SOIC-8_5.23x5.23mm_P1.27mm
U4: OPTICAL-TSL2561T(6P-3.8X2.6MM); TMB6-1.55-3.8X2.6MM; MPN TSL2561T
U5, U6: AD8603; TSOT-23-5
Y1: Crystal_GND2; Resonator_SMD_Murata_CSTxExxV-3Pin_3.0x1.1mm
Z1, Z2, Z3: Selector_default
sx1: sx~; sx70

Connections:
+1V1: C1.1, C2.1, C3.1, U1.23 (DVDD), U1.45 (VREG_VOUT), U1.50 (DVDD)
+3.3V: C5.1, C6.1, C7.1, C8.1, C9.1, C10.1, C11.1, C12.1, C13.1, C14.1, R4.1, R11.1, R12.1, R34.2, U1.1 (IOVDD), U1.10 (IOVDD), U1.22 (IOVDD), U1.33 (IOVDD), U1.42 (IOVDD), U1.43 (ADC_AVDD), U1.44 (VREG_IN), U1.48 (USB_VDD), U1.49 (IOVDD), U2.3 (OUT), U3.8 (VCC), U4.1 (VDD), U5.5 (V+), U6.5 (V+), Z1.1, sx1.F+
/FF: U1.29 (GPIO18), sx1.FF
/FT: R9.1, sx1.FT
/FT-3: R9.2, R10.1, U1.38 (GPIO26_ADC0)
/GTD-3: R5.1, R6.2, U1.2 (GPIO0)
/GTD-6: R6.1, sx1.GTD
/LED1: D5.1 (K), U1.16 (GPIO13)
/LED2: D6.1 (K), U1.15 (GPIO12)
/MOTOR: R21.2, sx1.MOTOR
/QSPI_SCLK: U1.52 (QSPI_SCLK), U3.6 (CLK)
/QSPI_SD0: U1.53 (QSPI_SD0), U3.5 (DI(IO0))
/QSPI_SD1: U1.55 (QSPI_SD1), U3.2 (DO(IO1))
/QSPI_SD2: U1.54 (QSPI_SD2), U3.3 (IO2)
/QSPI_SD3: U1.51 (QSPI_SD3), U3.7 (IO3)
/QSPI_SS: R3.2, R4.2, U1.56 (QSPI_SS), U3.1 (~CS)
/S1F: R15.1, Z2.1, sx1.S1F
/S1F-3: R15.2, R16.1, U1.4 (GPIO2)
/S1F_FPC: Q3.3 (D), R33.2, Z2.2, Z2.3, sx1.S1F_FPC
/S1F_PF_MCU: R31.2, U1.34 (GPIO22)
/S1T: R13.1, Z3.2, Z3.3, sx1.F-, sx1.S1T
/S1T-3: R13.2, R14.1, U1.3 (GPIO1), Z3.1
/S2: U1.30 (GPIO19), sx1.S2, sx1.S2+
/S3: U1.9 (GPIO7), sx1.S3
/S4A_3: R29.1, R30.2, U1.14 (GPIO11), sx1.S4A
/S4B: R30.1, sx1.S4B
/S5: U1.8 (GPIO6), sx1.S5
/S8: R17.1, sx1.S8
/S8-3: R17.2, R18.1, U1.6 (GPIO4)
/S9: R19.1, sx1.S9
/S9-3: R19.2, R20.1, U1.5 (GPIO3)
/SCL0: R12.2, U1.32 (GPIO21), U4.4 (SCL)
/SDA0: R11.2, U1.31 (GPIO20), U4.6 (SDA)
/SFH_H: C15.2, R7.2, R27.1, U1.39 (GPIO27_ADC1), U5.1
/SFH_L: R8.2, U1.40 (GPIO28_ADC2), U6.1
/SOL1-: D3.2 (A), Q1.3 (D), sx1.SOL1-
/SOL1_MCU: R22.1, U1.12 (GPIO9)
/SOL2-: D4.2 (A), Q2.3 (D), sx1.SOL2-
/SOL2_MCU: R24.1, U1.28 (GPIO17)
/USB_D+: J2.2, R1.2
/USB_D-: J2.1, R2.2
/XIN: U1.20 (XIN), Y1.3
/XOUT: R35.1, Y1.1
/~USB_BOOT: J1.2, R3.1
GND: C1.2, C2.2, C3.2, C4.2, C5.2, C6.2, C7.2, C8.2, C9.2, C10.2, C11.2, C12.2, C13.2, C14.2, D2.2 (A), J1.1, J3.1, Q1.2 (S), Q2.2 (S), Q4.2 (E), R5.2, R10.2, R14.2, R16.2, R18.2, R20.2, R23.1, R25.1, R26.1, R28.2, R29.2, R33.1, U1.19 (TESTEN), U1.57 (GND), U2.1 (GND), U3.4 (GND), U4.2 (ADDR), U4.3 (GND), U5.2 (V-), U5.3 (+), U6.2 (V-), Y1.2, Z1.2, Z1.3, sx1.GND, sx1.S2-
unnamed: C15.1, D2.1 (K), R7.1, U5.4 (-)
unnamed: D5.2 (A), D6.2 (A), R34.1
unnamed: Q1.1 (G), R22.2, R23.2
unnamed: Q2.1 (G), R24.2, R25.2
unnamed: Q3.1 (G), Q4.3 (C), R32.2
unnamed: Q4.1 (B), R31.1
unnamed: R21.1, U1.7 (GPIO5)
unnamed: R2.1, U1.46 (USB_DM)
unnamed: R1.1, U1.47 (USB_DP)
unnamed: R35.2, U1.21 (XOUT)
unnamed: R27.2, R28.1, U6.3 (+)
unnamed: R8.1, R26.2, U6.4 (-)
VBUS: D1.2 (A), J3.2
VCC: C4.1, D1.1 (K), D3.1 (K), D4.1 (K), Q3.2 (S), R32.1, U2.2 (IN), sx1.S1C, sx1.SOL1+, sx1.SOL2+, sx1.VCC

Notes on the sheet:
Flash
Meter0
Power
Crystal
IF Sonar: high means button got pressed ELSE : low
Controller (RP2040 )
Meter1
SCL1
SDA1
USB

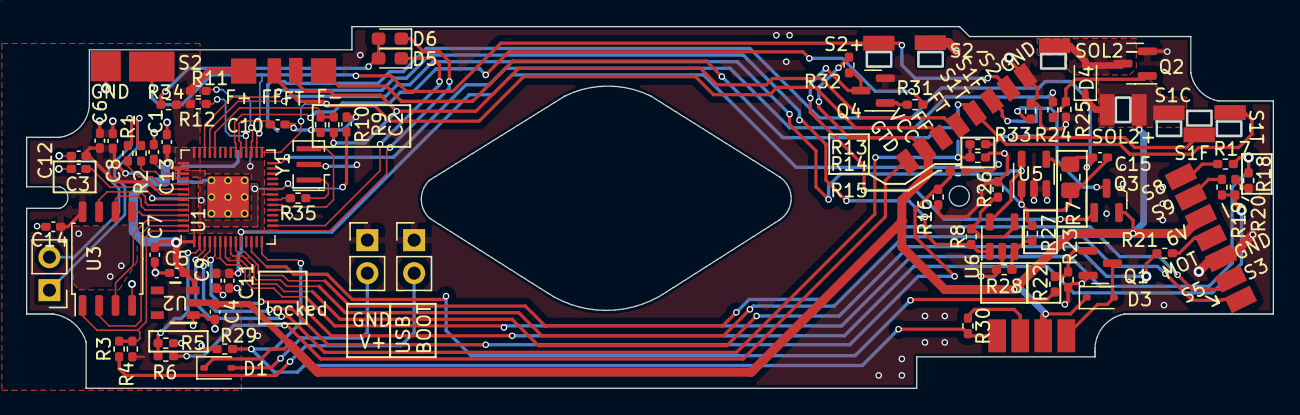
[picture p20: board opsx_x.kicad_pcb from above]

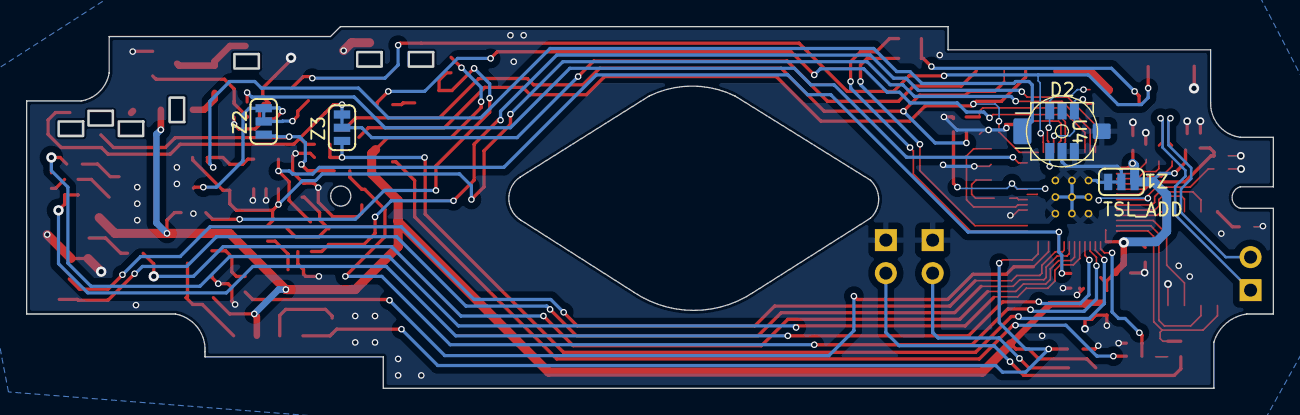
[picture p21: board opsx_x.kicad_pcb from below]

Board: 2 copper layers, 95.9 x 27.8 mm, 74 parts (5 on the bottom side), 59 nets.

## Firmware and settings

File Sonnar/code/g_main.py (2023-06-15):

"""
正常调试版本，适合组装后使用
"""
from machine import Pin,PWM,ADC,I2C
import tsl2561,time,ssd1306,pcf8575

# Change Shutter_Delay_Back
# Change Motor Sequence S5


_CAMERA_DBG_ = True
Red_Button_Pressed = 1
if_focused = False
flash_connected = False
LM_ADDR = 41

de_bounce_time = 1
de_bounce_count = 10
adc_de_bonuce_count = 70

display_addr = 60
have_disp = False
encoder_addr = 32
have_enc = False
enc_pins = [4,5,6,7]
# Code Start at "#End of Config"

# Config Output Pins <See Pins.xls>
shutter_pin = 9
apture_pin = 17
motor_pin = 5
LED_Y_PIN = 12
LED_B_PIN = 13
S1F_FBW_PIN = 22
FF_PIN = 11 # Flash Pin High to trigger
# End Config Output

# Config Input Pins <See Pins.xls>
S1F_PIN = 2 # Sw 1 Focus
S1T_PIN = 1 # Sw 1 Take Photo
S2_PIN = 14 # Flash Check Pin | SCL1
S3_PIN = 7
S5_PIN = 6
# End Config Input Pins

# Define Encoder Code
EC_ZERO = '1111'
EC_ONE = '0111'
EC_TWO = '1011'
EC_THREE = '0011'
EC_FOUR = '1101'
EC_FIVE = '0101'
EC_SIX = '1001'
EC_SEVEN = '0001'
EC_EIGHT = '1110'
EC_NINE = '0110'
EC_A = '1010'
EC_B = '0010'
EC_C = '1100'
EC_D = '0100'
EC_E = '1000'
EC_F = '0000'

# Config ShutterDelay  sht(1/n) or sht(n)s
ev7 = 600
ev75 = 440
ev8 = 280
ev85 =210
ev9 = 155
ev95 =120
ev10 = 97
ev105 = 70
ev11 = 48
ev115 = 40
ev12 = 33
ev125 = 29
ev13 = 25
ev135 = 23
ev14 = 21
ev145 = 20
ev15 = 19
ev16 = 18

ShutterSpeedHuman = {ev7:'1/2', ev75:'1/3', ev8:'1/4', ev85:'1/6', ev9:'1/8', ev95:'1/10', ev10:'1/15', ev105:'1/20', ev11:'1/30', ev115:'1/45', ev12:'1/60',
                     ev125:'1/90', ev13:'1/125', ev135:'1/180', ev14:'1/250', ev145:'1/360', ev15:'1/500', ev16:'1/1000'}
# End Config ShutterDelay
#a=sht1000
#End of Config

def read_enc():
    result = ""
    for i in enc_pins:
        result += str(pcf.pin(i))
    #print(result,pcf.pin(1))
    return result

def plug_encoder():
    ec = read_enc()
    #ec = EC_ZERO #delete
    #print(ec)
    if ec == EC_ZERO:
        display.text('AUTO', 10, 2, 0)
        return 'A'
    elif ec == EC_ONE:
        display.text('B', 23, 2, 0)
        return 'B'
    elif ec == EC_TWO:
        display.text('T', 23, 2, 0)
        return 'T'
    elif ec == EC_THREE:
        display.text('1/2', 15, 2, 0)
        return ev7
    elif ec == EC_FOUR:
        display.text('1/4', 15, 2, 0)
        return ev8
    elif ec == EC_FIVE:
        display.text('1/6', 15, 2, 0)
        return ev85
    elif ec == EC_SIX:
        display.text('1/8', 15, 2, 0)
        return ev9
    elif ec == EC_SEVEN:
        display.text('1/10', 10, 2, 0)
        return ev95
    elif ec == EC_EIGHT:
        display.text('1/15', 10, 2, 0)
        return ev10
    elif ec == EC_NINE:
        display.text('1/20', 10, 2, 0)
        return ev105
    elif ec == EC_A:
        display.text('1/30', 10, 2, 0)
        return ev11
    elif ec == EC_B:
        display.text('1/60', 10, 2, 0)
        return ev12
    elif ec == EC_C:
        display.text('1/125', 5, 2, 0)
        return ev13
    elif ec == EC_D:
        display.text('1/250', 5, 2, 0)
        return ev14
    elif ec == EC_E:
        display.text('1/500', 5, 2, 0)
        return ev15
    elif ec == EC_F:
        display.text('1/1000', 1, 2, 0)
        return ev16
    
def showFrame():
    display.fill(0)
    display.fill_rect(0, 0, 128, 11, 1)
    display.vline(51, 0, 11, 0)
    display.vline(82, 0, 11, 0)
    
def meter():
    sensor.gain(16)
    try:
        lux = sensor.read()
    except ValueError:
        sensor.gain(1)
        lux = sensor.read()
    #print(lux,sensor.gain())
    if _CAMERA_DBG_:
        print("Lux = {0:.2f} \t\tGain = {1:.2f} \t\t".format(lux, sensor.gain()))
    lux -= 0.4
    if iso == '600':
        if 0.120<lux<=0.125: 
            return ev75,lux
        elif 0.125<lux<=0.1385:
            return ev8,lux
        elif 0.1385<lux<=0.152:
            return ev85,lux
        elif 0.152<lux<=0.185:
            return ev9,lux
        elif 0.185<lux<=0.22:
            return ev95,lux
        elif 0.22<lux<=0.275:
            return ev10,lux
        elif 0.28<lux<=0.345:
            return ev105,lux
        elif 0.345<lux<=0.468:
            return ev11,lux
        elif 0.468<lux<=0.58:
            return ev115,lux
        elif 0.58<lux<=0.802:
            return ev12,lux
        elif 0.802<lux<=1.115:
            return ev125,lux
        elif 1.115<lux<=1.6:
            return ev13,lux
        elif 1.6<lux<=2.35:
            return ev135,lux
        elif 2.35<lux<=3.4:
            return ev14,lux
        elif 3.4<lux<=4.2:
            return ev145,lux
        elif 4.2<lux<=10:#
            return ev15,lux
        elif 10<lux:#
            return ev16,lux
        else:
            return ev7,lux

# Inital camera
def camera_init():
    global sensor,plugI2c,plugscan,pcf,display,have_disp,have_enc,motor,shutter,apture,LED_Y,LED_B,FF,s2,s3,s5,s1t,s1f,S1F_FBW,ADC0,ADC1,iso
    lm_i2c = I2C(0,scl=Pin(21), sda=Pin(20), freq=400000)
    sensor = tsl2561.TSL2561(lm_i2c,41)
    plugI2c = I2C(1,scl=Pin(19), sda=Pin(18), freq=400000)
    
    plug_i2c_add = plugI2c.scan()
    plugscan = bool(plug_i2c_add) and len(plug_i2c_add)<=5
    print(plugI2c.scan())
    
        
    shutter = PWM(Pin(shutter_pin))
    shutter.freq(20000)
    shutter.duty_u16(0)
    apture = PWM(Pin(apture_pin))
    apture.freq(70000)
    apture.duty_u16(0)
    
    motor = Pin(motor_pin,Pin.OUT, value=0)
    LED_Y = Pin(LED_Y_PIN, Pin.OUT,value = 1)
    LED_B = Pin(LED_B_PIN, Pin.OUT,value = 1)
    FF = Pin(FF_PIN, Pin.OUT,value = 0)
    S1F_FBW = Pin(S1F_FBW_PIN, Pin.OUT,value = 0)
    
    s2 = Pin(S2_PIN,Pin.IN,Pin.PULL_UP)
    s3 = Pin(S3_PIN,Pin.IN,Pin.PULL_UP)
    s5 = Pin(S5_PIN,Pin.IN,Pin.PULL_UP)
    s1f = Pin(S1F_PIN,Pin.IN)
    s1t = Pin(S1T_PIN,Pin.IN)
    
    f = open('./dat/iso.txt')
    iso = f.readline()
    iso.replace(" ","")
    f.close()
    if _CAMERA_DBG_:
        print("ISO at %s!"%iso)
    if iso == '600':
        LED_Y.value(0)
        #display.text('600', 55, 2, 0)
    else:
        LED_B.value(0)
        #display.text('70', 60, 2, 0)
    
    if plugscan and encoder_addr in plug_i2c_add:
        pcf = pcf8575.PCF8575(plugI2c, encoder_addr)
        pcf.port = 0x0ff
        print("have plug")
        have_enc = True
        
    if plugscan and display_addr in plug_i2c_add:
        
        display = ssd1306.SSD1306_I2C(128, 32, plugI2c,addr=display_addr) # 设置宽度，高度和I2C通信
        have_disp = True
        display.contrast(0)
        print("have disp")
        showFrame()
        display.text('OFF', 94, 2, 0)
        if iso == '600':
            display.text('600', 55, 2, 0)
        else:
            display.text('70', 60, 2, 0)
        
        if have_enc:
            """
            enc = plug_encoder()
            if True or enc == 'A':
                shut_speed,raw = meter()                 
                display.text(str(ShutterSpeedHuman[shut_speed])+'s', 8, 23)
                if len(str(raw))>7:
                    raw = str(raw)[0:7]
                display.text(str(raw), 64, 23)
            elif enc == 'B':
                func = 'B'
            elif enc == 'T':
                func = 'T'
            """
            pass
        else:
            if not have_enc:
                display.text('Auto', 10, 2, 0)
            shut_speed,raw = meter()                 
            display.text(str(ShutterSpeedHuman[shut_speed])+'s', 8, 23)
            if len(str(raw))>7:
                raw = str(raw)[0:7]
            display.text(str(raw), 64, 23)
        display.show()
        
    

def close_led():
    LED_Y.value(1)
    LED_B.value(1)
    
def led_iso():
    if iso == '600':
        LED_Y.value(0)
    else:
        LED_B.value(0)

def de_bounce_read_pins(pin_list):
    global de_bounce_time,de_bounce_count
    pin_value = [0]*len(pin_list)
    for i in range(de_bounce_count):
        for j in range(len(pin_list)):
            pin_value[j] += pin_list[j].value()
        time.sleep_ms(de_bounce_time)
    for i in range(len(pin_value)):
        pin_value[i] = round(pin_value[i]/de_bounce_count)
        if i >1:
            i = 1
    return pin_value

def apture_engage():
    apture.duty_u16(65535)
    
def apture_disengage():
    apture.duty_u16(0)
        
        
def shut(Shutter_Delay, f="1"):
    
    #f = open('sht_cal.txt','a')
    #f.write("{0:.2f}\n".format(Shutter_Delay))
    #f.close()
    
    if _CAMERA_DBG_:
        print("Taking Picture")
        print("Shutter start to close!")
    # Shutter Close
    shutter.duty_u16(65535)
    time.sleep_ms(30)
    shutter.duty_u16(30000)
    if _CAMERA_DBG_:
        print("Shutter closed!")

    time.sleep_ms(30) # wait for shutter to fully close
    #time.sleep_ms(3000) #Delete

    # Motor starts moving
    motor.value(1)
    if _CAMERA_DBG_:
        print("Motor Start Moving")

    # Move until mirror reach correct position
    while True:
        if s3.value() == 1:
            motor.value(0)
            if _CAMERA_DBG_:
                print("Motor Stoped!")
            break
        
    if f=='0': #Engage apture 
        apture_engage()
        if _CAMERA_DBG_:
            print("apture_engage")
    
    time.sleep_ms(18) # Y delay
    
    shutter.duty_u16(0) #open shutter
    if _CAMERA_DBG_:
        print("Shutter Start to Open, Exposure Starts")

    # Start Exposure
    if f == '0': #Flash
        if _CAMERA_DBG_:
            print("Flash Mode!")
        gap = int(Shutter_Delay- 47)
        if gap < 0:
            gap = 0
        time.sleep_ms(47)
        FF.value(1)
        apture_disengage() # Apture goes back
        FF.value(0)
        time.sleep_ms(gap)
    
    elif f == '1': #Normal
        if _CAMERA_DBG_:
            print("Normal Mode!")
        time.sleep_ms(Shutter_Delay)
    
    elif f == 'B': #B mode
        if _CAMERA_DBG_:
            print("B Mode!")
        time.sleep_ms(15)
        while True:
            dbpv = de_bounce_read_pins([s1f,s1t])
            foc = dbpv[0]
            tak = dbpv[1]
            time.sleep_ms(3)
            if tak != Red_Button_Pressed:
                break

    elif f == 'T': # T mode
        if _CAMERA_DBG_:
            print("T Mode!")
        
        # Wait until Button Released
        while True:
            dbpv = de_bounce_read_pins([s1f,s1t])
            foc = dbpv[0]
            tak = dbpv[1]
            if tak != Red_Button_Pressed:
                break
        # Wait until Button Pressed Again
        while True:
            dbpv = de_bounce_read_pins([s1f,s1t])
            foc = dbpv[0]
            tak = dbpv[1]
            time.sleep_ms(3)
            if tak == Red_Button_Pressed:
                break
    # End Exposure
    
    #time.sleep_ms(3000) #Delete

    # Close Shutter
    shutter.duty_u16(65535) # Close Shutter
    if _CAMERA_DBG_:
        print("Shutter Closing!")
    time.sleep_ms(30) # wait until shutter fully closed
    shutter.duty_u16(30000) # Keep Shutter Closed
    if _CAMERA_DBG_:
        print("Shutter Closd. Exposure Finished")
    time.sleep_ms(18)

    #start ejacting film
    motor.value(1)
    if _CAMERA_DBG_:
        print("Motor Working!")
    
    #time.sleep_ms(2000) #Delete

    # wait until film fully ejact
    while True:
        if s5.value() == 0:
        #if s5.value() == 1:#Delete
            motor.value(0)
            shutter.duty_u16(0)
            break


#Taking Photo, St = Shutter delay
def Take_Photo(St,Shut_Mode):
    #meter()
    LED_Y.value(1)
    LED_B.value(1)
    print("EXP Time:",str(St)," Flash:",str(Shut_Mode))
    """
    if not flash_connected:
        shut(St);
    else:
        shut(St,'0');
    """
    shut(St,Shut_Mode);
    print("Taken!")
    #led_iso()
    LED_Y.value(0)
    #return
#time.sleep_ms(1000)

def test_cam():
    time.sleep_ms(3800)
    LED_Y.value(1)
    shutter.duty_u16(65535)
    time.sleep_ms(3800)
    shutter.duty_u16(0)
    motor.value(1)
    LED_Y.value(0)
    
def Cam_Operation():
    global if_focused, CAMERA_DBG
    while True:
        # See if flash is connected
        flash_connected = not s2.value()
        #print(flash_connected, s2.value())
        # Get Redbutton Value
        dbpv = de_bounce_read_pins([s1f,s1t])
        foc = dbpv[0]
        tak = dbpv[1]
        if have_enc:      
            display.fill_rect(0, 0, 50, 11, 1)  
            enc = plug_encoder()
            display.show()
        # If button pressed half way and not focused
        if foc == Red_Button_Pressed and if_focused == False:
            S1F_FBW.value(1);  #delete
            if have_disp:
                showFrame()
                if iso == '600':
                    display.text('600', 55, 2, 0)
                else:
                    display.text('70', 60, 2, 0)
            
            # Meter Mode Select
            #Flash inserted
            if flash_connected: 
                shut_mode = '0'
                if (not have_enc) or enc =='A':
                    St = ev11
                    display.text(str(ShutterSpeedHuman[St])+'s', 8, 23)
                    _,raw = meter()
                    if len(str(raw))>7:
                        raw = str(raw)[0:7]
                    display.text(str(raw), 64, 23)
                    display.text(str(ShutterSpeedHuman[St])+'s', 8, 23)
                elif enc != 'B' and enc != 'T':
                    St = plug_encoder()
                    if St < ev11:
                        St = ev11
                    _,raw = meter()
                    if len(str(raw))>7:
                        raw = str(raw)[0:7]
                    display.text(str(raw), 64, 23)
                    display.text(str(ShutterSpeedHuman[St])+'s', 8, 23)
                else:
                    if have_disp:
                        display.text('---', 94, 2, 0)
                        display.fill_rect(0,12,128,52,0)
                        #display.text('Shutter open until button release', 8, 23)
                        display.text('Not Support', 8, 23)
                    continue

                if have_disp:
                    display.text('FLASH', 86, 2, 0)
                    display.text('1/30', 10, 2, 0)
            
            # No Flash
            else:
            # No Selector or Set to AUTO
                if (not have_enc) or enc == 'A': 
                    if not have_enc and have_disp:
                        display.text('Auto', 10, 2, 0)
                    if have_disp:
                        display.text('OFF', 94, 2, 0)
                    
                    #meter
                    St,raw = meter()
                    shut_mode = '1' # '0'-flash; '1'-normal; 'B'- B; 'T' - T
                    if have_disp:
                        if len(str(raw))>7:
                            raw = str(raw)[0:7]
                        display.text(str(raw), 64, 23)
                        display.text(str(ShutterSpeedHuman[St])+'s', 8, 23)
                    """
                    if St >= ev7:
                        LED_B.value(0)
                    else:
                        LED_B.value(1)
                    """
                
                # Select B Mode
                elif enc == 'B':
                    shut_mode = 'B'
                    St = ev11
                    if not have_enc and have_disp:
                            #display.text('B', 10, 2, 0)
                            pass
                    if have_disp:
                        display.text('OFF', 94, 2, 0)
                        display.fill_rect(0,12,128,52,0)
                        #display.text('Shutter open until button release', 8, 23)
                        display.text('Open When Press', 8, 23)
                # Select T Mode
                elif enc == 'T':
                    shut_mode = 'T'
                    St = ev11
                    if not have_enc and have_disp:
                            #display.text('B', 10, 2, 0)
                            pass
                    if have_disp:
                        display.text('OFF', 94, 2, 0)
                        display.fill_rect(0,12,128,52,0)
                        #display.text('Shutter open until button release', 8, 23)
                        display.text('Press to Stop', 8, 23)
                
                else:
                    St = plug_encoder()
                    _,raw = meter()
                    shut_mode = '1' # '0'-flash; '1'-normal; 'B'; 'T'
                    if have_disp:
                        display.text('OFF', 94, 2, 0)
                        display.fill_rect(0,12,128,52,0)
                        if len(str(raw))>7:
                            raw = str(raw)[0:7]
                        display.text(str(raw), 64, 23)
                        display.text(str(ShutterSpeedHuman[St])+'s', 8, 23)
            """
            todo : Select shutter speed
            """

            if have_disp: 
                #display.text(str(ShutterSpeedHuman[St])+'s', 8, 23)
                display.show()
            if_focused = True
            print("Focusing!")
            if _CAMERA_DBG_:
                print(dbpv)
        
        if foc != Red_Button_Pressed and if_focused == True:
            S1F_FBW.value(0); #delete
            if_focused = False
            print("Stop Focus")
            if _CAMERA_DBG_:
                print(dbpv)

        # Button Fully Pressed -> Take Photo
        if tak == Red_Button_Pressed:
            Take_Photo(St, shut_mode) 
            #Take_Photo(ev7, shut_mode) #delete
            #Take_Photo(St, 'B') #delete
            #Take_Photo(St, 'T') #delete
            if _CAMERA_DBG_:
                print(dbpv)
    

if __name__ == "__main__":
    camera_init()
    #test_cam()
    #shut(1000)
    Cam_Operation()
    #apture_engage()
    #LED_Y.value(1)
    #LED_B.value(1)
    #shut(a)
    while True:
        #meter()
        #time.sleep_ms(1000)
        #test_cam1()
        #time.sleep_ms(2000)
        #shut(meter())
        break

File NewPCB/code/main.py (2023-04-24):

from machine import Pin,PWM,ADC
import time

_CAMERA_DBG_ = True
Red_Button_Pressed = 1
if_focused = False
de_bounce_time = 1
de_bounce_count = 10
adc_de_bonuce_count = 70
# Code Start at "#End of Config"

# Config Output Pins <See Pins.xls>
shutter_pin = 9
apture_pin = 17
motor_pin = 5
LED_Y_PIN = 12
LED_B_PIN = 13
S1F_FBW_PIN = 22
# End Config Output

# Config Input Pins <See Pins.xls>
S1F_PIN = 2 # Sw 1 Focus
S1T_PIN = 1 # Sw 1 Take Photo
S3_PIN = 7
S5_PIN = 6
ADC_STAGE1_PIN = 27
ADC_STAGE2_PIN = 28
# End Config Input Pins

# Config ShutterDelay  sht(1/n) or sht(n)s
sht4s = 4000
sht3s = 3000
sht2s = 2000
sht1s = 1000
sht2 = 600
#ev75 = 440
sht4 = 280
sht6 =210
sht8 = 155
sht10 =120
sht15 = 97
sht20 = 70
sht30 = 48
#ev115 = 40
sht60 = 33
#ev125 = 29
sht125 = 25
#ev135 = 23
sht250 = 21
#ev145 = 20
sht500 = 19
sht1000 = 18
# End Config ShutterDelay

#End of Config

# Inital camera
def camera_init():
    global motor,shutter,apture,LED_Y,LED_B,s3,s5,s1t,s1f,S1F_FBW,ADC0,ADC1,iso
    shutter = PWM(Pin(shutter_pin))
    shutter.freq(20000)
    shutter.duty_u16(0)
    apture = PWM(Pin(apture_pin))
    apture.freq(70000)
    apture.duty_u16(0)
    
    motor = Pin(motor_pin,Pin.OUT, value=0)
    LED_Y = Pin(LED_Y_PIN, Pin.OUT,value = 1)
    LED_B = Pin(LED_B_PIN, Pin.OUT,value = 1)
    S1F_FBW = Pin(S1F_FBW_PIN, Pin.OUT,value = 0)
    
    s3 = Pin(S3_PIN,Pin.IN,Pin.PULL_UP)
    s5 = Pin(S5_PIN,Pin.IN,Pin.PULL_UP)
    s1f = Pin(S1F_PIN,Pin.IN)
    s1t = Pin(S1T_PIN,Pin.IN)
    
    ADC0 = ADC(Pin(ADC_STAGE1_PIN))  # 初始化ADC
    ADC1 = ADC(Pin(ADC_STAGE2_PIN))  # 初始化ADC
    
    f = open('./dat/iso.txt')
    iso = f.readline()
    iso.replace(" ","")
    f.close()
    if _CAMERA_DBG_:
        print("ISO at %s!"%iso)
    if iso == '600':
        LED_Y.value(0)
    else:
        LED_B.value(0)

def close_led():
    LED_Y.value(1)
    LED_B.value(1)
    
def led_iso():
    if iso == '600':
        LED_Y.value(0)
    else:
        LED_B.value(0)

def de_bounce_read_pins(pin_list):
    global de_bounce_time,de_bounce_count
    pin_value = [0]*len(pin_list)
    for i in range(de_bounce_count):
        for j in range(len(pin_list)):
            pin_value[j] += pin_list[j].value()
        time.sleep_ms(de_bounce_time)
    for i in range(len(pin_value)):
        pin_value[i] = round(pin_value[i]/de_bounce_count)
        if i >1:
            i = 1
    return pin_value

def apture_engage():
    apture.duty_u16(32700)
    
def apture_disengage():
    apture.duty_u16(0)

def meter():
    read_voltage0 = 0
    read_voltage1 = 0
    for i in range(adc_de_bonuce_count):
        read_voltage0 += ADC0.read_u16()*3000/65535   # 读取ADC通道0的数值并根据ADC电压计算公式得到GPIO26引脚上的电压
        read_voltage1 += ADC1.read_u16()*3000/65535   # 读取ADC通道0的数值并根据ADC电压计算公式得到GPIO26引脚上的电压
        time.sleep_ms(1)
    read_voltage0 = read_voltage0/adc_de_bonuce_count
    read_voltage1 = read_voltage1/adc_de_bonuce_count
    if _CAMERA_DBG_:
        print("1st stage voltage = {0:.2f}mV \t\t  2nd stage voltage = {1:.2f}mV \t\t".format(read_voltage0, read_voltage1))
    
        
    

def shut(Shutter_Delay, f="1"):
    if _CAMERA_DBG_:
        print("Taking Picture")
    if _CAMERA_DBG_:
        print("Shutter start to close!")
    shutter.duty_u16(65535)
    time.sleep_ms(18)
    shutter.duty_u16(10000)
    motor.value(1)
    if _CAMERA_DBG_:
        print("Motor Start Moving")
    while True:
        if s3.value() == 1:
            motor.value(0)
            if _CAMERA_DBG_:
                print("Motor Stoped!")
            break
        
    if f=='0': #Engage apture
        apture_engage() 
    time.sleep_ms(18) # Y delay
    
    shutter.duty_u16(0) #open shutter
    if _CAMERA_DBG_:
        print("Shutter Start to Open, Exposure Starts")

    # Start Exposure
    if f == '0':
        if _CAMERA_DBG_:
            print("Flash Mode!")
        gap=int(Shutter_Delay*0.3)
        time.sleep_ms(gap)
        fl.value(1)
        time.sleep_ms(gap)
        fl.value(0)
        apture_disengage() # Apture goes back
        time.sleep_ms(gap)
    elif f == '1':
        time.sleep_ms(Shutter_Delay)
    elif f == 'B':
        time.sleep_ms(15)
        while True:
            time.sleep_ms(3)
            if btn.value() == 1:
                break
    elif f == 'T':
        time.sleep(100)
        while True:
            time.sleep(3)
            if btn.value() == 0:
                break
    # End Exposure
    
    shutter.duty_u16(65535) # Close Shutter
    if _CAMERA_DBG_:
        print("Shutter Closing!")
    time.sleep_ms(20)
    shutter.duty_u16(10000) # Keep Shutter Closed
    if _CAMERA_DBG_:
        print("Shutter Closd. Exposure Finished")
    
    motor.value(1)
    if _CAMERA_DBG_:
        print("Motor Working!")
    while True:
        if s5.value() == 0:
            motor.value(0)
            shutter.duty_u16(0)
            break
        

def test_cam():
    time.sleep_ms(3800)
    LED_Y.value(1)
    shutter.duty_u16(65535)
    time.sleep_ms(3800)
    shutter.duty_u16(0)
    motor.value(1)
    LED_Y.value(0)
    
def test_cam1():
    global if_focused, CAMERA_DBG
    while True:
        dbpv = de_bounce_read_pins([s1f,s1t])
        foc = dbpv[0]
        tak = dbpv[1]
        if foc == Red_Button_Pressed and if_focused == False:
            #S1F_FBW.value(1);
            if_focused = True
            print("Focusing!")
            if _CAMERA_DBG_:
                print(dbpv)
        if foc != Red_Button_Pressed and if_focused == True:
            #S1F_FBW.value(0);
            if_focused = False
            print("Stop Focus")
            if _CAMERA_DBG_:
                print(dbpv)
        if tak == Red_Button_Pressed:
            meter()
            LED_Y.value(1)
            LED_B.value(1)
            shut(1000);
            print("Taken!")
            led_iso()
            
            if _CAMERA_DBG_:
                print(dbpv)
            #return
    
if __name__ == "__main__":
    camera_init()
    #test_cam()
    #shut(1000)
    test_cam1()
    while True:
        meter()
        time.sleep_ms(1000)

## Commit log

2023-04-18 PCB finished
    finished pcb designing, god bless it would work.
    [BOM_R1.xlsx, EV_SH2430.xlsx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]
2023-04-19 test appliance
    [opsx_x.DXF, opsx_x.SLDASM, opsx_x.SLDDRW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]
2023-04-20 Test Pin Holder for Bare Pcb
    [Test_Pin_Holder.STL, Test_pin_bottom_bare_pcb.STL, dumplicate.csv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]
2023-04-24 Meter not finish
    [EV_SH2430.xlsx]
2023-04-25 meter cal.
    [EV_SH2430.xlsx]
2023-05-05 Rev2 Finished
    [84952-4.step, BOM_right.xlsx, PinConfig.xlsx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]
2023-05-10 Body Controller
    [Controller_body.kicad_pcb, Controller_body.kicad_sch, PCF8575PWR.step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]
2023-05-10 flash_tested & PCB Rev 2.1
    [opsx_x.kicad_pcb]
2023-05-11 Organize files
    [84952-4.step, BOM_R1.xlsx, BOM_right.xlsx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]
2023-05-11 controller finished
    [Controller_body.kicad_pcb, Controller_body.kicad_sch]
2023-05-15 controller manufacture & todo list
    [Controller_body.csv, Controller_body.kicad_pcb, bom.csv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]
2023-05-16 repaired cliper
    [line_cliper_reverse.ipt, line_cliper_reverse.stl]
2023-05-20 cliper updated && fill in flash code finished
    [line_cliper.stl, rot_no_val_th.0005.ipt, rot_no_val_th.ipt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]
2023-05-22 code upgrade
    [Controller_body.kicad_pcb]
2023-05-23 case refined
    [Controller_body.kicad_pcb, oled.SLDPRT, 机身.SLDASM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]
2023-05-27 Body Controller 3D models
    [Case_Body_Control.STL, rot_no_val_sec_th.ipt, rot_no_val_sec_th.stl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]
2023-05-28 Body Controller Basic Function
    [rot_no_val_sec_th.ipt, rot_no_val_sec_th.stl, rot_no_val_th.ipt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]
2023-05-30 Assembled and tested
    [机身.SLDASM, 机身壳.SLDPRT, 机身壳.STEP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]
